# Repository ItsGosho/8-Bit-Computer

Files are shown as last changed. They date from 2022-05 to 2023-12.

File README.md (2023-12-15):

# 8-Bit-Computer
Бележки от създаването на 8-битовия компютър



- Библиотека с част от чиповете нарисувани са направени и качени в **KiCad Symbols**

- Идеята за проекта се води от книгата [Digital Computer Electronics - Albert Paul Marvino](https://www.amazon.com/Digital-computer-electronics-Albert-Malvino/dp/0070398615) и Ben Eater
- Имаме модулна архитектура - Всеки един от компонентите може да бъде изграден самостоятелно и да работи самостоятелно

- Като в нея има много компютърни архитектури, като една от тях и използваната тук е **SAP-1 (Simple as Possible)**

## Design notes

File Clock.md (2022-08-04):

# Clock:

- Синхронизира опрерациите в компютъра
- Начина по който това става е пускането на електрически сигнал през определен интервал:
- - Може да е автоматично през определен интервал. Броя пъти пускане на тока за една секунда ги измерваме в Hz-ове.
  - - Hz - Брой пъти действия за една секунда
  - - Може да забързваме честотата или пък да я забавяме
- - Може да е ръчно.
  - Може да сменяме между автоматично и ръчно

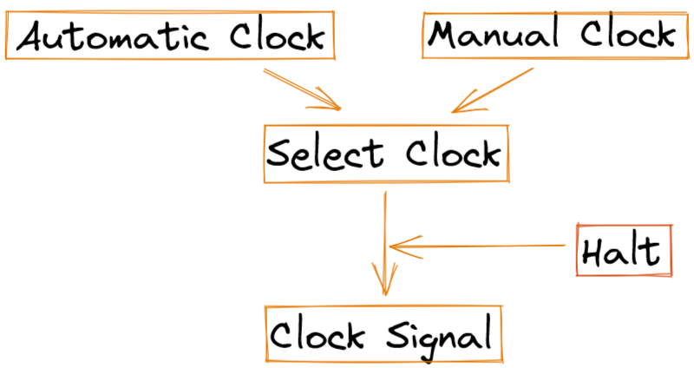
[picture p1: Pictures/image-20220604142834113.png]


### **Automatic Clock:**

- Ще работи **автоматично**. Ще подава сигнал през фиксирано време.
- Използваме за това нещо **555 Timer** в **Astable** състояние.
- **555-Timer.md**

### **Manual Clock:**

- Ще работи **ръчно**. Ние ще определяме кога да следващото подаване на сигнал.
- Използваме за това нещо **555 Timer** в **Monostable** състояние за **Debounce** на ръчният бутон.

- **Button Debouncing.md**

### **Select Clock:**

- Ще сменянме какъв да ни е **Clock-a** чрез **Switch** между **Astable** или **Monostable**
- Използваме за това нещо **555 Timer** в **Bistable** състояние за **Debounce** на Switch-a за смяната
- **Switch SPDT Debouncing.md**

### Halt: 

- Имаме **HALT** линия за **прекъсване** на **Clock-a**, която прекъсва връзката между **Select Clock** & **Clock Signal**

### Clock Signal:

- Изкарва периодичен сигнал, който синхронизира операциите ни.

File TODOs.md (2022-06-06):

1. Във файла Clock.md подробно ще опиша идеята на Clock-a.
   - Какво искаме да постигнем като цяло и какво му е идеята
   - 1 стъпка - Astable Clock - Подробно за какво идва реч
   - 2 стъпка - Monostable Clock - Подробно за какво идва реч
   - 3 стъпка -  Bistable Clock - Подробно за какво идва реч
   - Ще се постарая да сложа във кой файл може да се намери подробна информация

- Пренаредя пиновете на Clock модула

Links:

https://www.ilovefreesoftware.com/13/featured/free-websites-to-make-timing-diagram-online.html

https://circuitdigest.com/electronic-circuits/what-is-switch-bouncing-and-how-to-prevent-it-using-debounce-circuit

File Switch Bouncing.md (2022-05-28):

# **Switch Bouncing Problem:**

- При натискането на бутон е възможно за кратно да получим няколко бързи сигнала преди да се стабилизира.

- В бутона и две метални плочици, които се свързват при натискането му.
- Проблема обача е че докато се стабилизират прилипнали ще подскочат/рикошират една от друга
- Това ще доведе до няколко бързи сигнала

Пример:



### Различни варианти за справяне с този проблем:

1. **Използваме RC (Resistance-Capacitance):**



- Когато **не сме** **натиснали** бутона, то **кондензатора се зарежда през резистори R1 и R2**

- Когато **натиснем** бутона, то **кондензатора се разрежда през резистор R2**

- Когато се **разреди кондензатора**, то **напрежението пада до 0V** и **Inverter-a се пуска** и **имаме сигнал на Output**

- Цялото нещо с кондензатора ни кара да задържим малко повече бутона за да получим сигнал на **Output**-a

- **ОТ ГОЛЕМИНАТА НА КОНДЕНЗАТОРА И РЕЗИСТОРА ЗАВИСИ:**

- - С какво закъснение ще се отчете сигнала при Output след натискане на бутона
  - Колко време ще е нужно да не натискаме бутона преди следващото натискане

  **Тест**: Нека вдигнем кондензатора **(C1)** на **10** microfarad-a:

  - Сега **ако натискаме по-бързо бутона**, то **няма да имаме сигнал на Output**, защото не се е разредил кондензатора

  - Съответно трябва да го задържим малко повече за да го разредим напълно и да получим сигна на **Output**

  - Така **избягваме Bouncing-a**, тоест тези няколко бързи сигнала, които се получават, когато го задържим - няма да активират нашият изход, защото не са достатъчно дълги за да затворят веригата и разредят кондензатора напълно.

    - Както виждаме от снимката, първите ни 3 бързи натискания не са достатъчни да Discharge-нат кондезатор
    - 

**Charging**:



**Discharging**:



2. **Използваме 555 Timer:**

- При натискането на бутона:
- - Взимаме 5V-та от **-** на Set Comparator-a, като така го активираме (1.7V **+** > 0V **-**)
  - Set Comparator-a слага SR Latch-a в Output State (Q = 1) и Discharge-a спира
  - Докато е спрян Discharge-a, то няма какво да отнеме напрежението от + на Reset Comparator-a и започва да се вдигна напрежението.
  - Когато то достигне + >= 3.3V, то SR Latch-a отива в Discharge State 



- **ОТ ГОЛЕМИНАТА НА КОНДЕНЗАТОРА И РЕЗИСТОРА ЗАВИСИ ПРИ DISCHARGE-a:**
- - Каква ще е дължината на сигнала след натискането на бутона
  - Колко време ще е нужно да не натискаме бутона преди следващото натискане

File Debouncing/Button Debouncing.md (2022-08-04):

# **Button Bouncing Problem:**

- При натискането на бутон е възможно за кратно да получим няколко бързи сигнала преди да се стабилизира.

- В бутона и две метални плочици, които се свързват при натискането му.
- Проблема обача е че докато се стабилизират прилипнали ще подскочат/рикошират една от друга
- Това ще доведе до няколко бързи сигнала
- На някой дигитални устройства, който могат бързо да отговорят на сигнала това ще им създаде проблем

Пример:



### Различни варианти за справяне с този проблем:

1. **Използваме RC (Resistance-Capacitance):** (Hardware Solution)

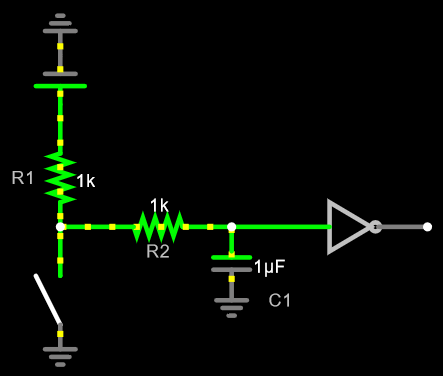
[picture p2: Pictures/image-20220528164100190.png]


- Когато **не сме** **натиснали** бутона, то **кондензатора се зарежда през резистори R1 и R2**

- Когато **натиснем** бутона, то **кондензатора се разрежда през резистор R2**

- Когато се **разреди кондензатора**, то **напрежението пада до 0V** и **Inverter-a се пуска** и **имаме сигнал на Output**

- Цялото нещо с кондензатора ни кара да задържим малко повече бутона за да получим сигнал на **Output**-a

- **ОТ ГОЛЕМИНАТА НА КОНДЕНЗАТОРА И РЕЗИСТОРА ЗАВИСИ:**

- - С какво закъснение ще се отчете сигнала при Output след натискане на бутона
  - Колко време ще е нужно да не натискаме бутона преди следващото натискане

  **Тест**: Нека вдигнем кондензатора **(C1)** на **10** microfarad-a:

  - Сега **ако натискаме по-бързо бутона**, то **няма да имаме сигнал на Output**, защото не се е разредил кондензатора

  - Съответно трябва да го задържим малко повече за да го разредим напълно и да получим сигна на **Output**

  - Така **избягваме Bouncing-a**, тоест тези няколко бързи сигнала, които се получават, когато го задържим - няма да активират нашият изход, защото не са достатъчно дълги за да затворят веригата и разредят кондензатора напълно.

    - Както виждаме от снимката, първите ни 3 бързи натискания не са достатъчни да Discharge-нат кондезатор
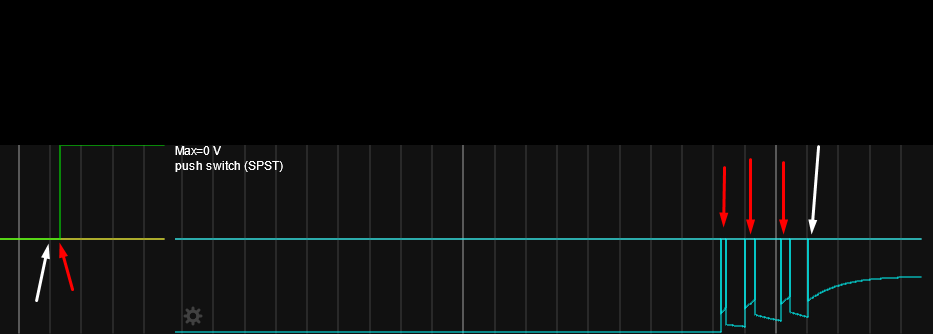
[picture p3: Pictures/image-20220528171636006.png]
    - 

**Charging**:

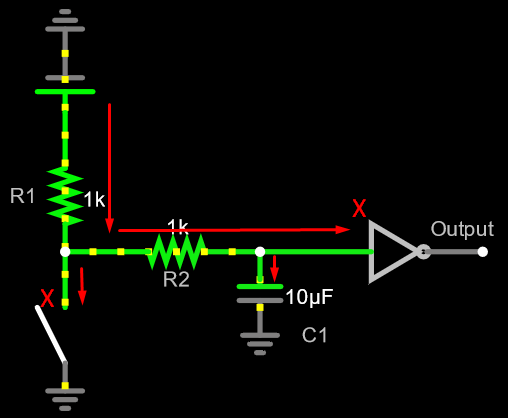
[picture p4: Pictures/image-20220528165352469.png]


**Discharging**:

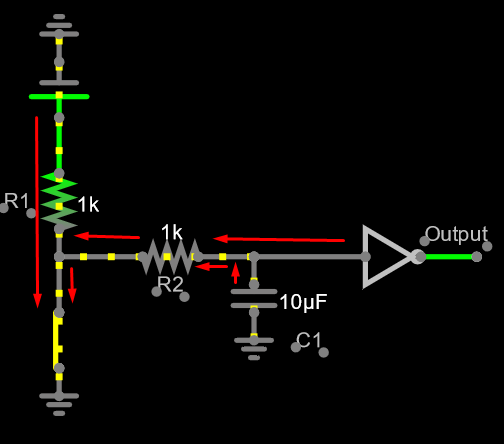
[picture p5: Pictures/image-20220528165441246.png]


2. **Използваме 555 Timer:** (Hardware Solution)

- При натискането на бутона:
- - Взимаме 5V-та от **-** на Set Comparator-a, като така го активираме (1.7V **+** > 0V **-**)
  - Set Comparator-a слага SR Latch-a в Output State (Q = 1) и Discharge-a спира
  - Докато е спрян Discharge-a, то няма какво да отнеме напрежението от + на Reset Comparator-a и започва да се вдигна напрежението.
  - Когато то достигне + >= 3.3V, то SR Latch-a отива в Discharge State 

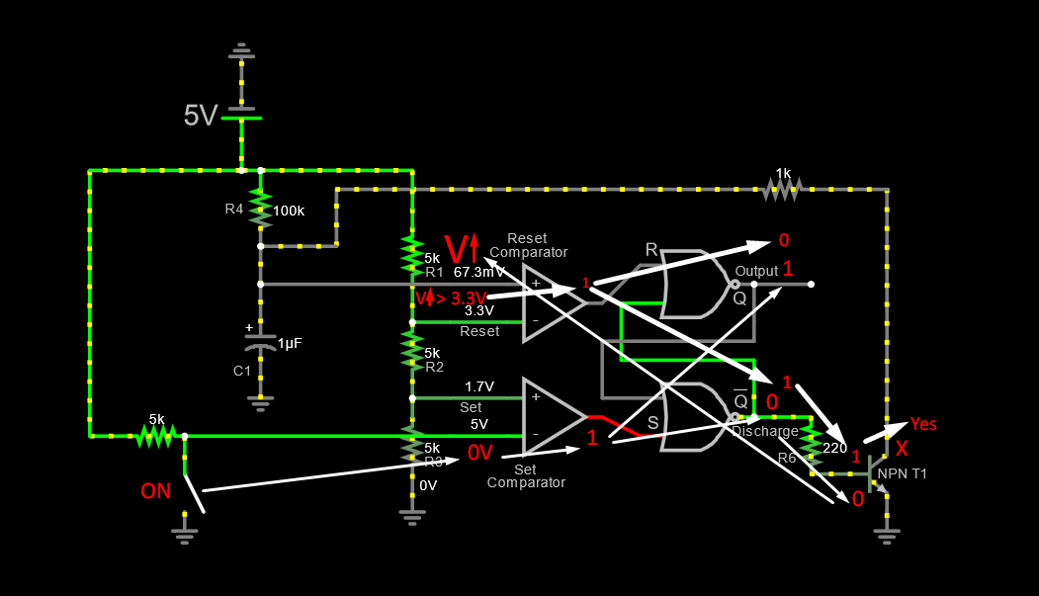
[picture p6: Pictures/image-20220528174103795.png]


- **ОТ ГОЛЕМИНАТА НА КОНДЕНЗАТОРА И РЕЗИСТОРА ЗАВИСИ ПРИ DISCHARGE-a:**
- - Каква ще е дължината на сигнала след натискането на бутона
  - Колко време ще е нужно да не натискаме бутона преди следващото натискане

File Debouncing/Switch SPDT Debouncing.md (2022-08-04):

# **Switch SPDT Bouncing Problem:**

- Switch-a избира състояние и остава на него
- При SPDT Switch-a може да избираме между две състояниа на които да останем

Bouncing:

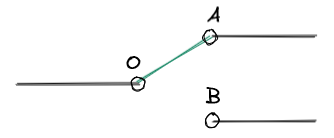
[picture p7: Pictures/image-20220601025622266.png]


- Когато сменяме от A към B или обратното от B към А се получава същото рикоширане както при Button
- Тук обаче рикоширането **НЕ е м/у двете състояния** (**A -> B**, **B -> A**, **A -> B**, **B -> A** ... **A -> B**):



- Рикоширането **Е между новото състояние е междинно такова**:

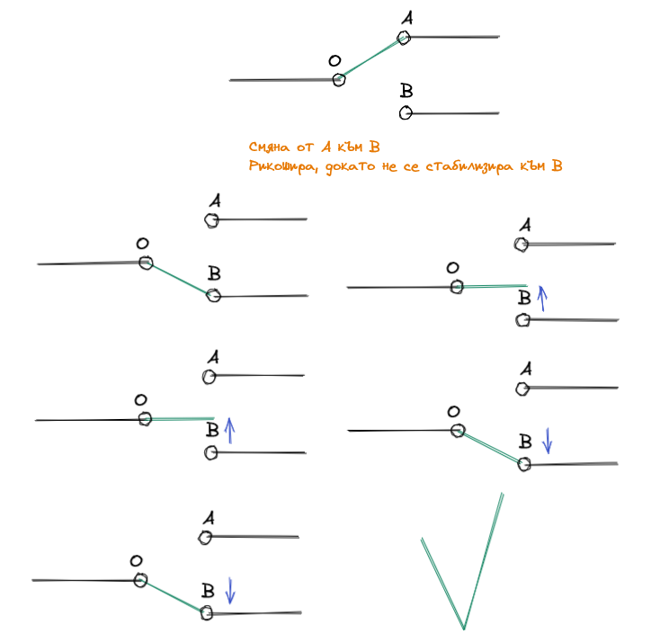
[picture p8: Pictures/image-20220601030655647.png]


### Различни варианти за справяне с този проблем:

1. **SR Latch:**

- Ако използваме SR Latch, който два входа да са свързани към тези на SPDT Switch-a лесно си решаваме проблема.
- Това става така, защото когато сменим от едно състояние в друго и се получи Bouncing-a от новото състояние към междинното:
- - SR Latch изхода няма да се промени, колкото и пъти да се подава новия вход от нулев такъв след първоначалното

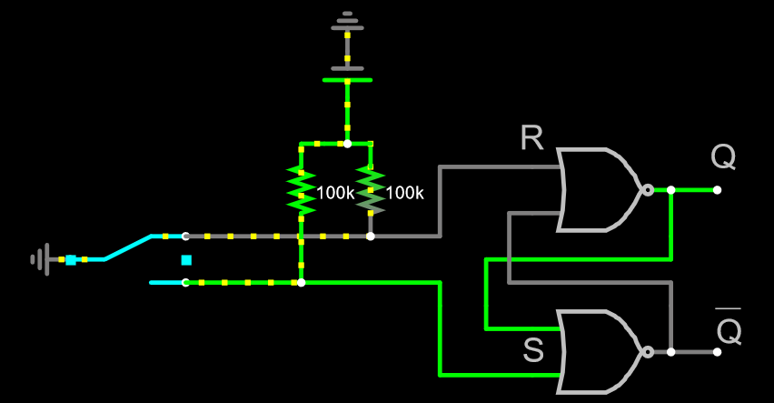
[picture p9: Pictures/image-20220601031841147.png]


- Резисторите нарочно са там, а не само един към Ground, защото когато влезе в междинно състояние няма да имаме никакво съпротивление
- Вече SPDT Switch-a ни става дигитален.

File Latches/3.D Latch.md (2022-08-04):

# D Latch:

- **D Latch** е акроним на **Data Latch**

- То е **Multivibrator** от тип **Bistable**

- Реализира се с **SR Latch**, *2 бр.* **AND Gate**, **Inverter**.

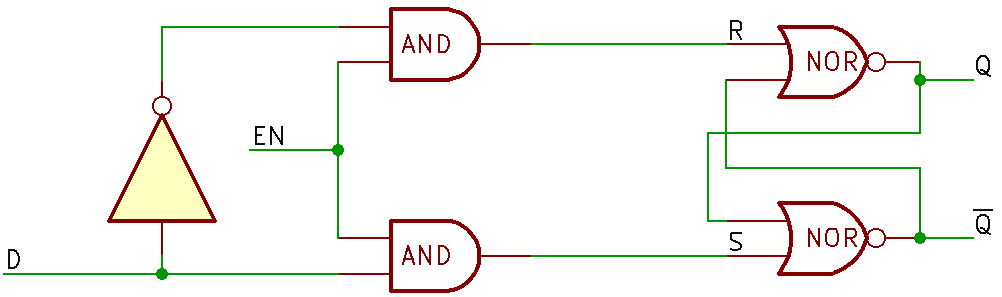
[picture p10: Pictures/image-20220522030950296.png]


**D Latch** в [CircuitJS](https://www.falstad.com/circuit/circuitjs.html)

- Чрез експериментиране може да видим какво се случва във веригата
- Файл: **/CircuitJS/d_latch.circuitjs.txt**

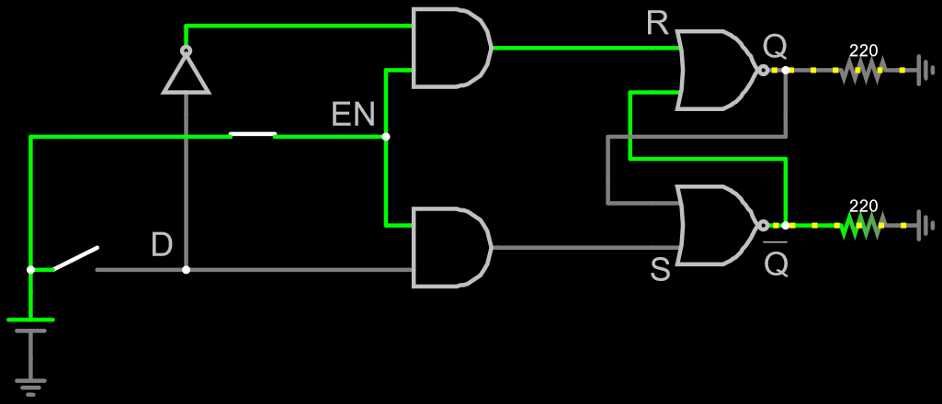
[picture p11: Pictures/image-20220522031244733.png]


- Той **надгражда SR Latch**, като позволява да определяме **дали може да се сменя състоянието на Latch-a чрез EN** и смяната на състоянието да става чрез **един вход** **D**
- Отново **не знаем** **началното** **състоянието** на **SR Latch**, ако **EN не е включен**.
- **Винаги** при подаването на **EN** без **D**,  Latch-a ще премине в **Reset (R)** състояние **заради Inverter-a**, който **постоянно подава сигнал**.
- Как би **изглеждал изхода** от **D Latch** при **примерно** подаване на сигнали:
- - **[DrawIo](https://app.diagrams.net/)** Timing Diagram
  - Файл: **/DrawIo/D_Latch_Timing_Diagram.drawio**

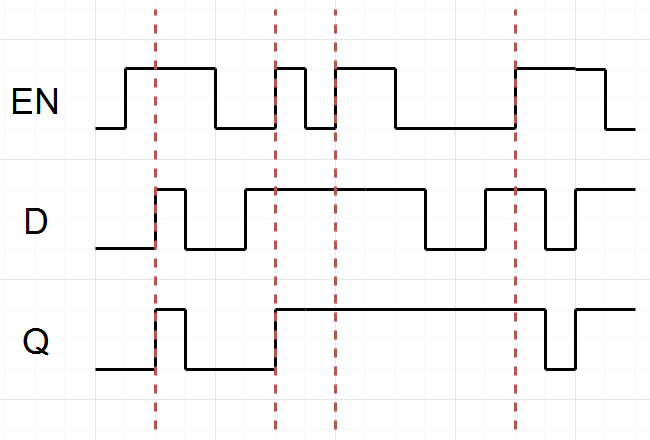
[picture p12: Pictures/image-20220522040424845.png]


- Както виждаме от диаграмата, *изхода* на **Q** *зависи* от D, което *зависи* от **EN**. 

- Когато **EN** е включен, то **Q** *следва* **D** *1:1*, ако **EN** бъде **изключен** то **Q** остава **последното състояние** на **D**.

| EN | D | Q | Q Inverted |
| ---- | ---- | ---- | :--- |
| 0 | 0 | Q | Q Inverted |
| 0 | 1 | Q | Q Inverted |
| 1 | 0 | 0 | 1 |
| 1 | 1 | 1 | 0 |

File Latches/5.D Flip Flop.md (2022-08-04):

# **D Flip Flop**

- То е **Multivibrator** от тип **Bistable**
- **Надгражда** D Latch, като се реализира с **Clock** вместо **Enable (EN)**

**D Flip Flop** в [CircuitJS](https://www.falstad.com/circuit/circuitjs.html)

- Чрез експериментиране може да видим какво се случва във веригата
- Файл: **/CircuitJS/d_flip_flop.circuitjs.txt**

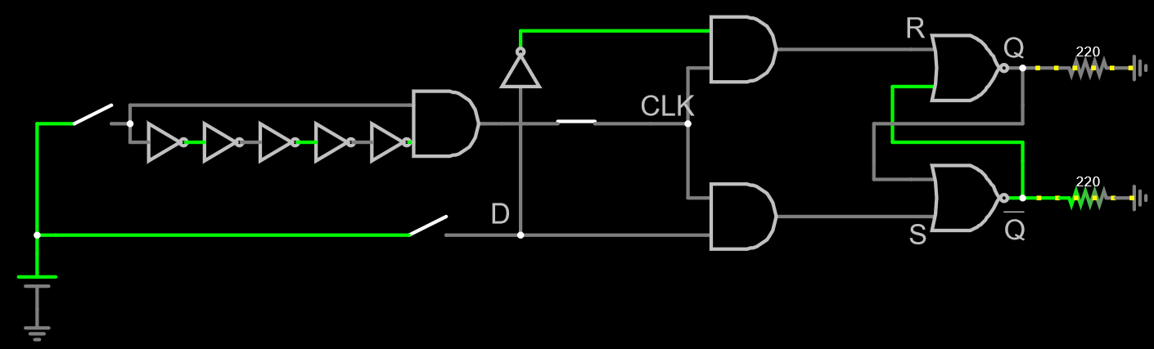
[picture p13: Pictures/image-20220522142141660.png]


- Как би **изглеждал изхода** от **D Flip Flop** при **примерно** подаване на сигнали:
- - **[DrawIo](https://app.diagrams.net/)** Timing Diagram
  - Файл: **/DrawIo/D_Flip_Flop.drawio**

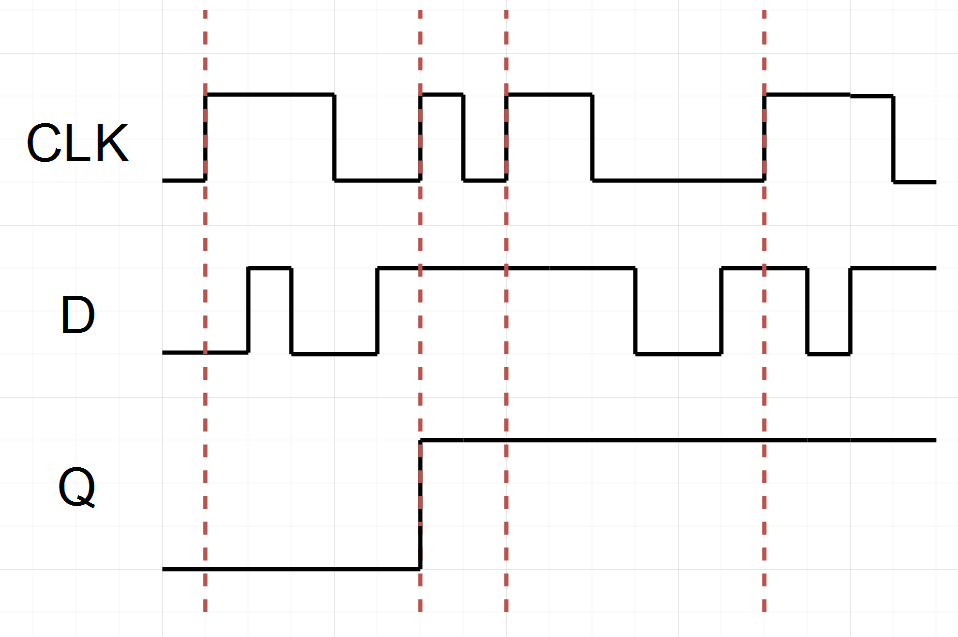
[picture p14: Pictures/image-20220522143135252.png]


| CLK  | D | Q | Q Inverted |
| ---- | ---- | ---- | --- |
| 0 | 0 | Q | Q Inverted |
| 0 | 1 | Q | Q Inverted |
| 1 | 0 | 0 | 1 |
| 1 | 1 | 1 | 0 |

- Таблицата е същата с тази на **D Latch**, но вече сигнала се **взима** само при **първоначалното** подаване на **сигнал**.

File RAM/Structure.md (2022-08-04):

# Structure:

### Address Module:

- В нашият модул, който използваме за паметта (**IC 74189 64 Bit RAM**) вече имаме изградена система за адресиране *(избиране на ред/адрес от паметта)*.

- Тази система за адресиране се състои от **4** входа, като те **бинарно** репрезентират **адрес/ред** в **паметта**.

- - Имаме входове **A0**,**A1**,**A2**,**A3**. Ако **искаме да изберем даден адрес** ще трябва да подадем **следните стойности на входовете**:

  - | A0   | A1   | A2   | A3   | Address |
    | ---- | ---- | ---- | ---- | ------- |
    | 0    | 0    | 0    | 0    | 0       |
    | 1    | 0    | 1    | 0    | 10      |
    | 0    | 1    | 1    | 1    | 7       |
    | 1    | 1    | 1    | 1    | 15      |

  - **Как се декодират и менажират адресите в паметта**, може да видим в **RAM-Idea.md**

- Въпреки, че **вече имаме изградена система** за адресиране в **IC 74189** ние **искаме да я надградим**:
- - Ръчен режим - ръчно ще изберем адрес от паметта
  - Автоматичен режим - на следващият clock сигнал от bus-a ще дойде адреса

#### Реализиране:

- Ще **сменяме режимите**  между *автоматичен* и *ръчен* с прост **Slide Switch**
- Ще имаме **LED индикация** в **кой режим се намираме** (*автоматичен*, *ръчен*)
- Ще имаме **4 битов DIP Switch** за **избиране на адрес при ръчен режим**.
- Ще имаме **74LS157 Quad 2-1 Line Mux**, който избира от коя страна (*автоматична*, *ръчна*) ще се взима сигнала
- - Работи  точно като дигиталният Switch, който правих. Тук имаме няколко канала между, които се сменя.
  - *CircuitJS/digital_switch_simplified.circuitjs.txt*
  - Примерно имаме **A0**,**B0**,**A1**,**B1** **входове** за сигнал, **Y0** и **Y1** **изходи** за резултат и **Select** вход за избор.
  - Ако **Select = 1**, то **Y0 = A0** и **Y1 = A1**
  - Ако **Select = 0**, то **Y0 = B0** и **Y1 = B1** 
- Ще имаме **74LS173 4-Bit D Register**, който ще ни помогне за това  да имаме **Clock** в **Address Module**-a.

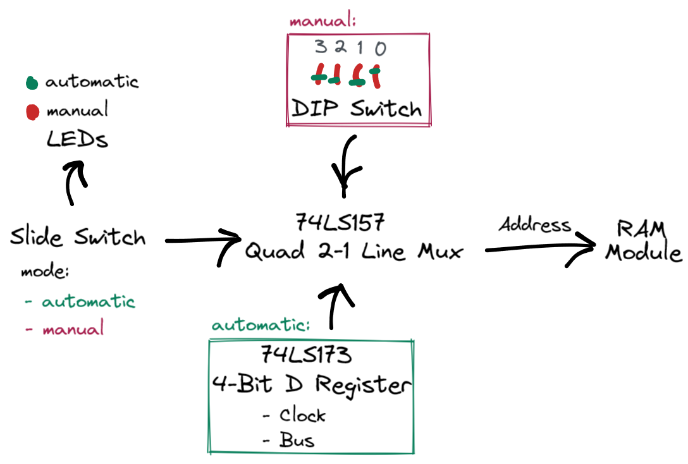
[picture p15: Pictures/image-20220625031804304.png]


### Data Module:

- В нашият модул, който използваме за паметта (**IC 74189 64 Bit RAM**) вече имаме изградена система за залагане на данни по избран адрес.
- Въпреки, че **вече имаме изградена система** за залагане на данни по избран адрес в **IC 74189** ние **искаме да я надградим**:
- - Ръчен режим - ръчно ще заложим данните на избран адрес
  - Автоматичен режим - на следващият clock сигнал от bus-a ще дойдат данните за избарния адрес

#### Реализиране:

- Ще използваме **Slide Switch**-a от **Address Module** за смяна на режимите (*автоматичен*/*ръчен*)
- Ще използваме същата **LED** индикация от **Address Module**
- Ще имаме **8 битов DIP Switch** за **избиране на данни при ръчен режим**.
- Ще имаме **Push Button**, който ще е **активен в ръчен режим** и при **натискане ще запише избраните данни на избрания адрес**
- Ще използваме **3** броя **74LS157 Quad 2-1 Line Mux**:
- - **2** **от тях** ще са за данните (от къде идват)
  - **1 от тях** ще е за записващият сигнал:
  - - Ръчен режим - **Push Button**
    - Автоматичен режим - **Clock**

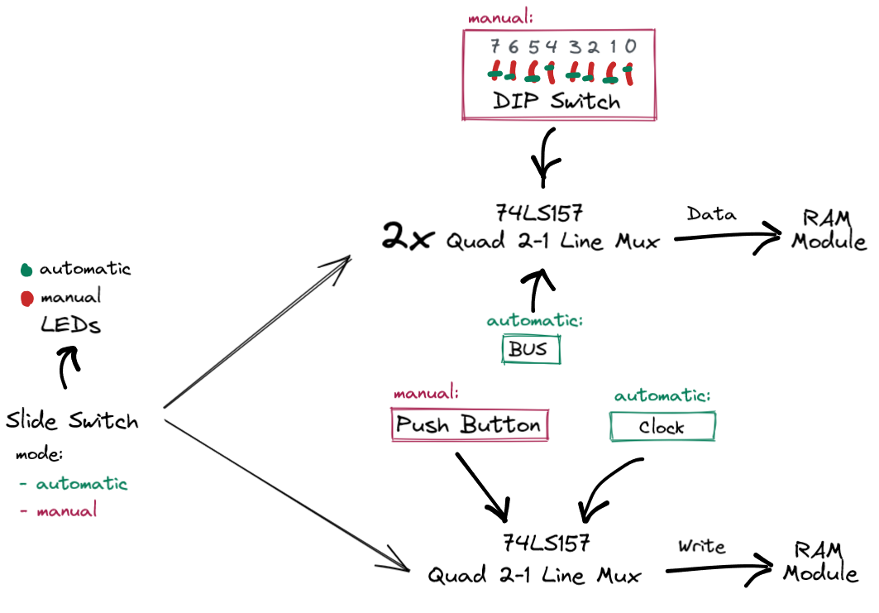
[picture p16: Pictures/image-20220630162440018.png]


#### Проблеми:

- **1:** 
  - Със стандартният дизайн при смяна на режимите (ръчен/автоматичен) често trigger-ваме write сигнала.
  - Това се получава от 74LS157 Quad 2-1 Line Mux. 
  - При смяна на Line дори и двата сигнала пр. A0 и B0 да са HIGH, то Y0 ще премине през LOW за кратко време, което време е достатъчно да trigger-не write-a на паметта.

- **2:**
  - Със стандартният дизайн използваме RC (Resistor-Capacitor) за да хванем Rising Edge-a на Clock-a.
  - Това нещо също довежда до проблеми по-нагоре.

**Реш. 1:**

- Push Button-a ще подава HIGH сигнал към 74LS157
- Clock-a също ще подава HIGH сигнал към 74LS157
- Резултата от 74LS157 ще бъде обърнат HIGH -> LOW, което ще активира записването

**Реш. 2:**

- Използваме останалите свободни пинове на 74LS00 (NAND Gate) и 74LS04 (Inverter) за да хванем Rising Edge-a на Clock.
- Ако закачим един и същи сигнал към двата входа на NAND Gate-a ще обърнем сигнала т.е може да го използваме като Inverter
- Ако закачим два входа към двата входа на NAND Gate-a и резултата го обърнем (т.е го закачим пак) ще получим AND от двата входа

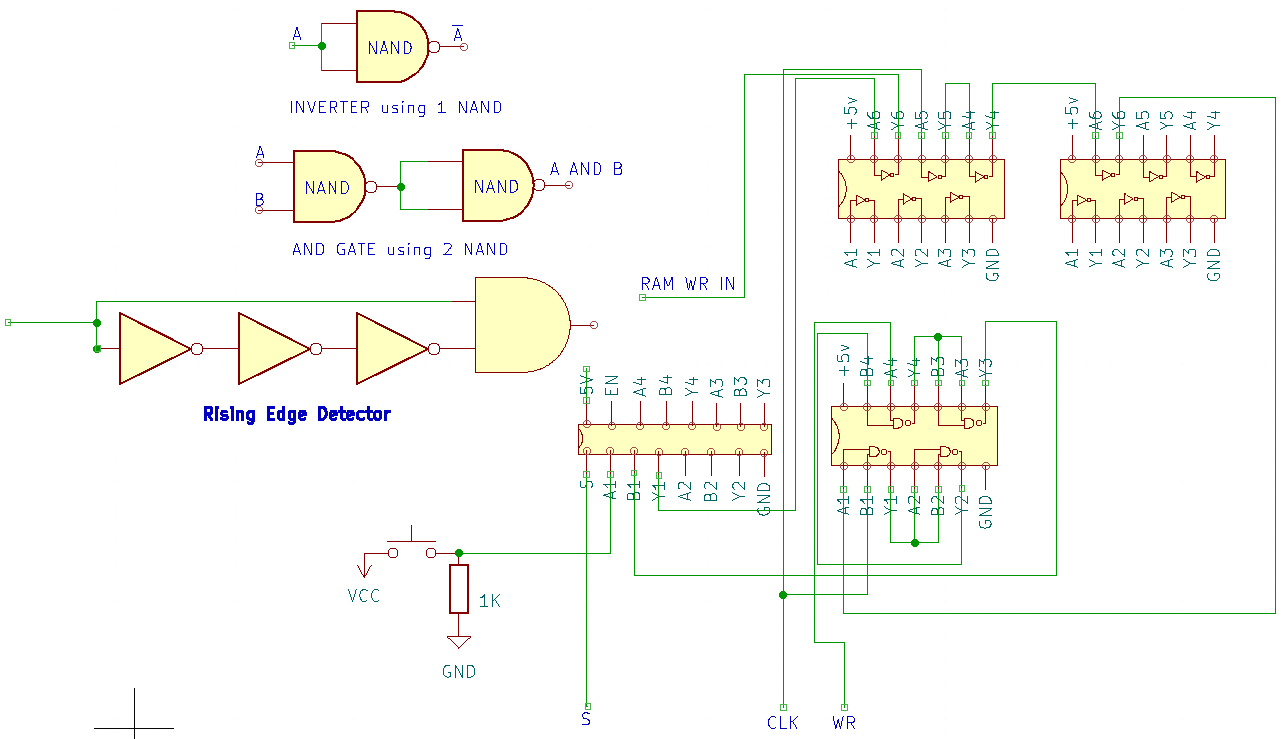
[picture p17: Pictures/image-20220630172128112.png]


### RAM Module:

- Имаме **2** бр. **74189: 64-bit RAM (4-bit words)**
  - Адресите им са свързани една с друга
  - Адресите им са свързани с **Address Module**
  - Единият държи **долните 4 бита**, а другият **горните 4 бита**.
  - Входа на данните е свързан с **Data Module**. Така имаме **16 броя 8-bit words**.
  - Изходите са свързани с **74LS04: Inverter**, защото на този чип изхода ни дава данните обърнати
  - Вече нормализираните данни чрез **74LS04: Inverter** са свързани с **74LS245: 8-bit bus transceiver** за да може правилно да ги изкараме на буса
- Имаме **2** бр. **74LS04: Inverter** за нормализиране на данните от рамта преди пускането на бус лентата.
  - Част от неговите входове, които не се използват при **RAM Module** се използват при **Data Module** за да ни помагнат да отстраним проблеми там
- Имаме **1** бр. **74LS245: 8-bit bus transceiver** за **правилна комуникация с бус лентата**

### Summary:

Имаме **Switch**, който сменя режимите между **ръчен** и **автоматичен**. Когато изберем режим адреса и данните ще дойдат или от нас през **DIP Switch**-овете или от **BUS** лентата. При ръчният режим след като сме избрали адрес и данни, натискаме **Push Button**-a и записваме на избраният адрес данните.

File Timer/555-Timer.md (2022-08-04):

# 555 Timer:

- Генерира електрически сигнал през определено време.
- Има две състояния Charging (Output), Discharging (No output)

Според информацията, която намерих в интернет за неговите "вътрешности" направих опит да го направя в **[CircuitJS](https://www.falstad.com/circuit/circuitjs.html)**, но изникнаха проблеми и се наложи да го преправя.

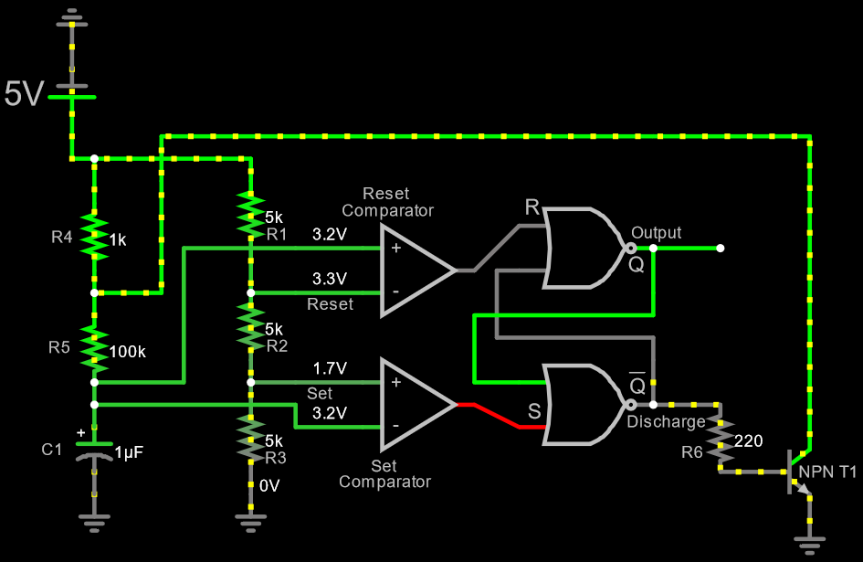
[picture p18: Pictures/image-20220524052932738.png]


- Resistor 1 (1k) променя само Time High
- Resistor 2 (100k) променя Time High и Time Low
- Capacitor (1u) променя Time High и Time Low значително

1. Създаваме **Voltage Divider** с **3** бр. 5k резистора:

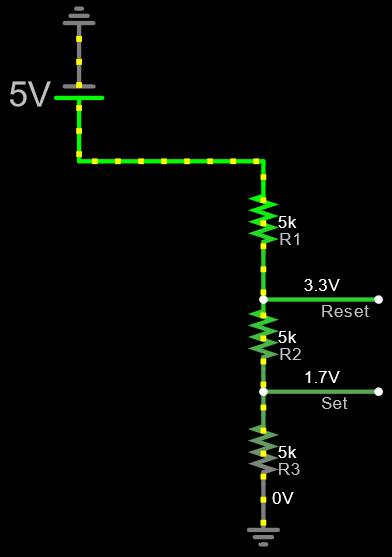
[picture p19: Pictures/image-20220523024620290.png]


- Идеята е да получим **различни нива на напрежение** м/у резисторите, който ще ни **служат за Comparator-ите после**.

2. Залагаме **2** бр. Comprator-и, които ще използваме за **Set & Reset** на бъдещият **SR Latch**.

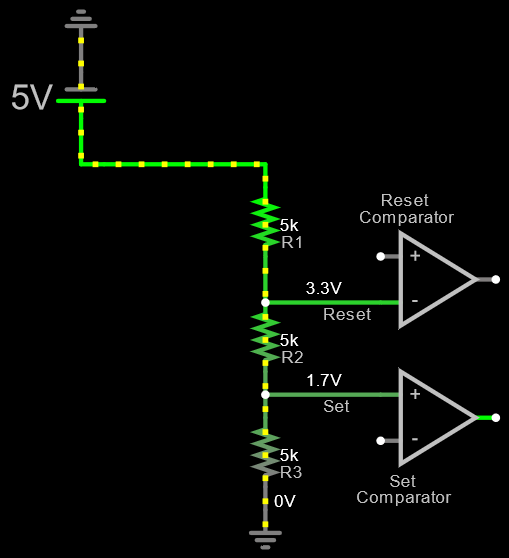
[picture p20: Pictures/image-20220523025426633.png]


- **Comparator сравнява напрежения**. Ако това на **+ > -** , то Comparator-a ще се активира и ще пуска ток, докато това условие е валидно.
- В нашият случай:
- - *Reset Comparator + > 3.3V*
  - *Set Comparator 1.7V > -*

3. Залагаме **SR Latch**, който ще ни позволи да запазим **двете нужни състояния** на нашият **555 Timer**:

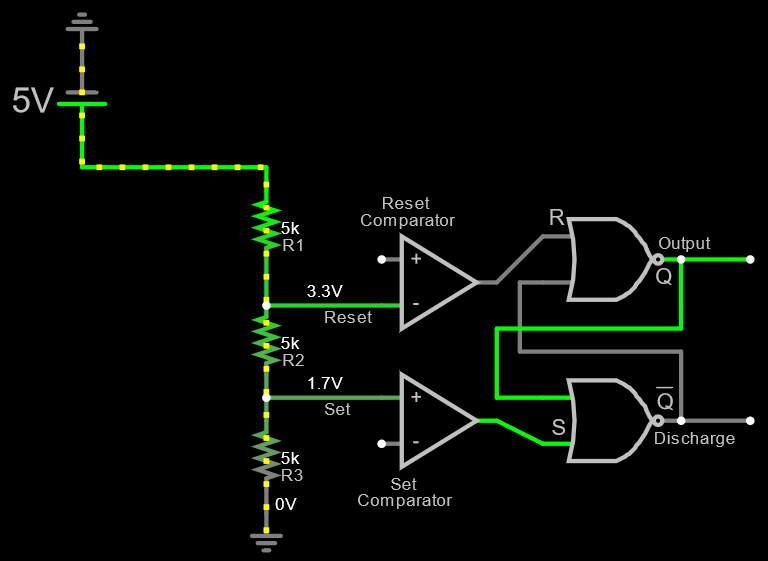
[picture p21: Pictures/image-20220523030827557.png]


- **SR Latch**-a ни е нужнен да **запомним** в което състояние се намираме - **Output** или **Discharge**
- При **Output** и **Discharge** периодите, **Reset** и **Set Comparator**-ите няма да бъдат активни. Затова използваме **SR Latch-a** да запомним **последното състояние** което е било избрано.

| Period | Reset Comparator + Voltage | Set Comparator - Voltage |
| --- | --- | --- |
| Output | Спада от 3.3V до 1.7V | Набира от 1.7V до 3.3V |
| Discharge | Набира от 1.7V до 3.3V | Спада от 3.3V до 1.7V |

4.  Основната контролираща линия:

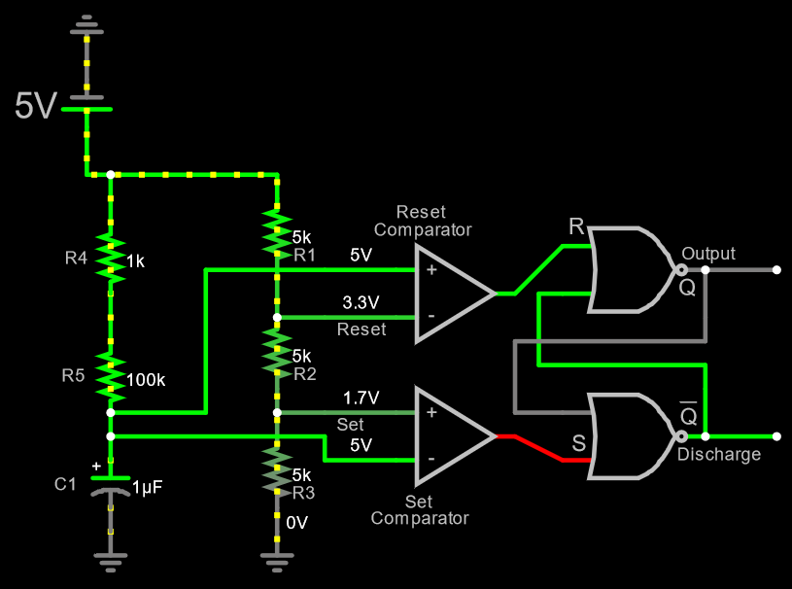
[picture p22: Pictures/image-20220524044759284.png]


- Заложи ли сме **2** бр. резистори в серия и **1** бр. кондензатор в серия с резисторите.
- Така ще **забавим времето за зареждане на кондензатора**, като това ще ни позволи **напрежението преди него да се качва по-бавно**.
- *Времето за качване на напрежението зависи от големината на кондензатора и съпротивлението в серия с него.*
- Note: Първият резистор (1K) е сложен нарочно, защото ще ни е нужен за Discharge логиката после.

5. Discharge логика:

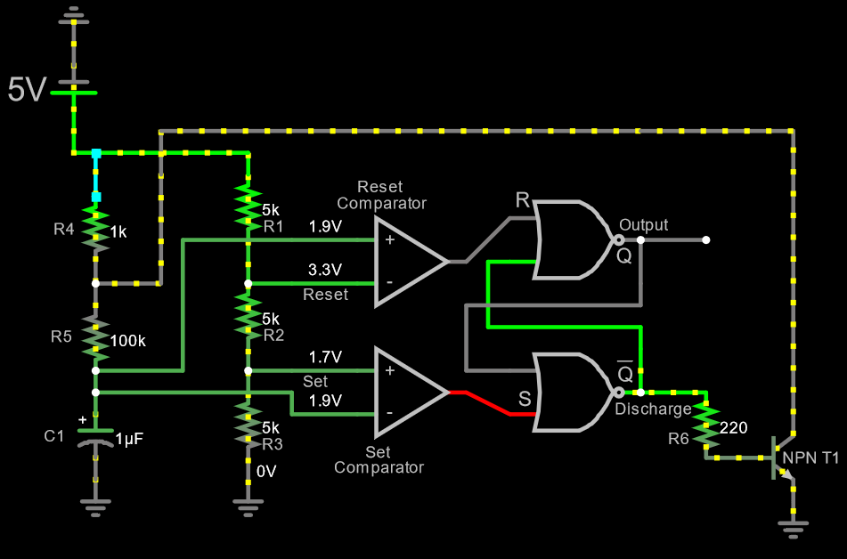
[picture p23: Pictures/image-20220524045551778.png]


- Залагаме, когато имаме състояние на **Discharge** при **SR Latch-a** да активираме **NPN Transistor**.
- NPN Transistor-a при активиране ще свързва **основната контролираща линия** с Ground.
- Когато се отвори **Discharge** линията, то тока от пътя **5V -> R4 -> R5 -> Reset Comparator, Set Comparator и C1** няма да следва този път вече, защото този на **Discharge** линията е с **по-малко съпротивление**.  Съотвено новият му път е **(5V -> R4 -> NPN T1 -> Ground)**
- **R5, C1, Reset Comparator и Set Comparator** ще загубят напрежение заради новата линия **5V -> R4 -> NPN T1 -> Ground** и тогава ще се активира **C1**. Вече имаме нова линия **C1 -> R5, Reset Comparator, Set Comparator -> NPN T1 -> Ground**. Сега постепенно напрежението на Reset Comparator и Set Comparator ще спада, докато отново не се активира Set Comparator-a. Тогава целият цикъл започва отначало.

**Charging Flow:**

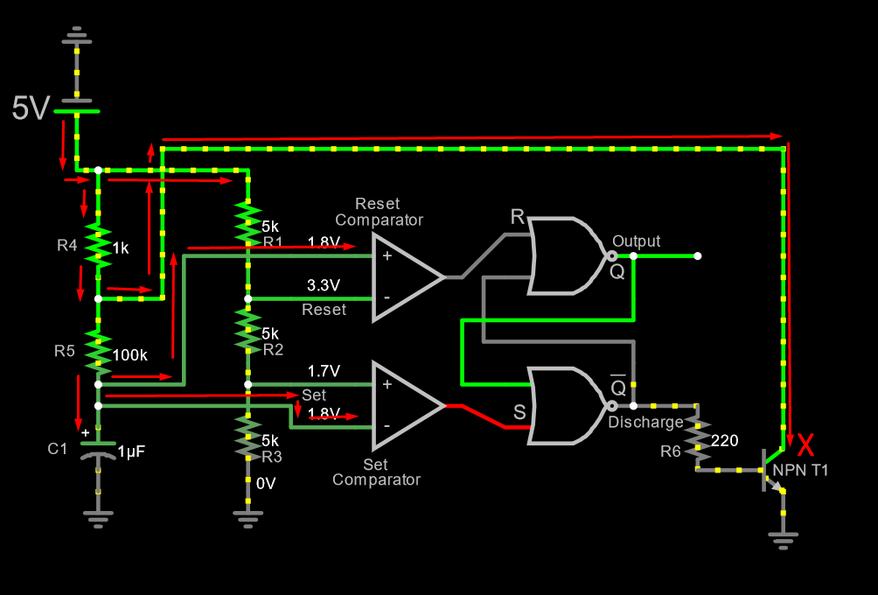
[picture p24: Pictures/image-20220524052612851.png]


**Discharging Flow:**



https://www.digikey.bg/en/resources/conversion-calculators/conversion-calculator-555-timer

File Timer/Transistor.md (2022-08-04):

https://www.seeedstudio.com/blog/2020/03/11/what-is-a-transistor-types-uses-working-principle/

https://learn.sparkfun.com/tutorials/transistors/all

https://www.physics-and-radio-electronics.com/electronic-devices-and-circuits/transistors/bipolarjunctiontransistor/bjtoperationmodes.html

https://www.allaboutcircuits.com/textbook/experiments/chpt-5/simple-op-amp/

https://www.youtube.com/watch?v=zpyK5Hy8d0c

https://www.youtube.com/watch?v=J4oO7PT_nzQ

- Чакам да дойдат PNP & NPN транзисторите за да мога да започна да ги ръчкам



1. Защо при еднакво напрежение и съпротивление имаме разлика във напрежението, когато е включен транзистор?







Изводите, които си правя тук:

- Emitter Current = Base Current + Collector Current

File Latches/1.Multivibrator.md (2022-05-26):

# Multivibrators:

- Идеята им е да задържат различни електрически състояния.
- Делят се на **3** категории:
- - **Bistable** - Имае **две** **стабилни** състояния 1 или 0 (**S-R Latch**, **D Latch**, **D Flip-Flop**)
  - **Monostable** - Има **едно** **стабилно** състояние (**Rising Edge Detector**)
  - **Astable** - Няма стабилно състояние. Постоянно сменя 1 или 0

### Resources:

**SR Latch:**

[Ben Eater]: https://www.youtube.com/watch?v=KM0DdEaY5sY&amp;list=PLowKtXNTBypGqImE405J2565dvjafglHU&amp;index=6
[All About Circuits]: https://www.allaboutcircuits.com/textbook/digital/chpt-10/s-r-latch/

**D Latch:**

[Ben Eater]: https://www.youtube.com/watch?v=peCh_859q7Q&amp;list=PLowKtXNTBypGqImE405J2565dvjafglHU&amp;index=7
[All About Circuits]: https://www.allaboutcircuits.com/textbook/digital/chpt-10/d-latch/

**D Flip Flop:**

[Ben Eater]: https://www.youtube.com/watch?v=YW-_GkUguMM&amp;list=PLowKtXNTBypGqImE405J2565dvjafglHU&amp;index=8
[All About Circuits]: https://www.allaboutcircuits.com/textbook/digital/chpt-10/edge-triggered-latches-flip-flops/

**Other useful:**

[Latch Circuits Questions]: https://www.allaboutcircuits.com/worksheets/latch-circuits/

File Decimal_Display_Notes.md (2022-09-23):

1. Искахме да обърнем бинарен вход репрезентиращ число пр. 0101 към десетично число 0101 -> 5
2. Имахме дисплейче (7 segment LED Display), което визуализира 7 различни чертички, като това коя ще се покаже зависи на кое от пинчетата му е подаден ток.
3. Съответно това дисплейче може лесно да визуализира стойности от 0 до 9 вкл.
4. Създаваме си една булева таблица между всички входове бинарни числа и нужните пинове които трябва да са пуснати на дислея за да го визуализира
5. Може лесно да създадем верига, която да изпълнява този combinational logic
6. Обаче нещата ще станат по-сложи, когато искаме да визуализираме 8 битово число като десетично, защото ще ни трябват 3 такива дисплея за да покажат нещо от 0 до 255.
7. Сложи, защото булевата таблица става гиганстска и веригака която трябва да създадем колосална
8. Тогава идва на помощ EEPROM, което е проста рам.
9. Обаче ние при булевите таблици имаме даден вход и изход
10. При рамта имаме адреси и стойност срещу тях
11. Може да използваме адресите на паметта да репрезентираме входа от булевата таблица, а стойноста на този адрес - изхода от булевата таблица
12. Само трябва предварително да сложим на ръка при даден вход какъв изход ще имам и сме готови
13. Още по-лесният вариант е да си напишем програм, която да пълни EEPROM-a автоматично за нас. Въпреки, че дори и след power off държи стойностите в него, то е по-лесно да си направим програма, която да го пълни. Така лесно може да имплементираме алгоритъм, който ни е нужен на нас.

EEPROM Programmer - Предварително записана памет с някакви данни.

- Как тези EEPROM програматори се различават от това да си го направя с Arduino ?!
- Ще напиша много готина и лесна за използване библиотека (един файл) за програмирането на 28C16 EEPROM-a

7 Segment Decimal Display: LTS547R



- След подаването на сигнал на даден PIN светва съответната чертичка.
- Примерно за да изобразим 7, ще трябва да подадем ток на пинове 3,4,1,7

- От тук може да си създадем таблица:

| Number | Pin 1 | Pin 2 | Pin 3 | Pin 4 | Pin 5 | Pin 6 | Pin 7 |
| --- | --- | --- | --- | --- | --- | --- | --- |
| `0` | *LOW* | **HIGH** | **HIGH** | **HIGH** | **HIGH** | **HIGH** | **HIGH** |
| `1` | *LOW* | *LOW* | *LOW* | **HIGH** | *LOW* | *LOW* | **HIGH** |
| `2` | **HIGH** | LOW | **HIGH** | **HIGH** | **HIGH** | **HIGH** | *LOW* |
| `3` | **HIGH** | *LOW* | **HIGH** | **HIGH** | *LOW* | **HIGH** | **HIGH** |
| `4` | **HIGH** | **HIGH** | *LOW* | **HIGH** | *LOW* | *LOW* | **HIGH** |
| `5` | **HIGH** | **HIGH** | **HIGH** | LOW | LOW | **HIGH** | **HIGH** |
| `6` | **HIGH** | **HIGH** | **HIGH** | LOW | **HIGH** | **HIGH** | **HIGH** |
| `7` | *LOW* | *LOW* | **HIGH** | **HIGH** | *LOW* | *LOW* | **HIGH** |
| `8` | **HIGH** | **HIGH** | **HIGH** | **HIGH** | **HIGH** | **HIGH** | **HIGH** |
| `9` | **HIGH** | **HIGH** | **HIGH** | **HIGH** | *LOW* | *LOW* | **HIGH** |

- Ние работим с бинарни числа в нашият 8 битов компютър.
- Съответно максималното число, което можем да трансферираме е 8 битово. 
- 8 бита могат да репрезентират като десетично число 1111 1111 = 255
- Нека да приемем, че нашият компютър е 3 битов, което означава максимална десетична стойност 111 = 7
- Искаме да визуализираме тази 3 битова стойност като десетично число на нашият дисплей. Може да си създадем булева таблица, която да репрезентира при дадена стойност от буса, кои пинове ще трябва да бъдат пуснати на дисплея за да визуализира стойноста правилно.

| Bus (Binary Value) | Display (Pins 1/7) |
| --- | --- |
| 000 **(0)** | 0111111 |
| 001 **(1)** | 0001001 |
| 010 **(2)** | 1011110 |
| 011 **(3)** | 1011011 |
| 100 **(4)** | 1101001 |
| 101 **(5)** | 1110011 |
| 110 **(6)** | 1110111 |
| 111 **(7)** | 0011001 |

- Тази Combination Logic може да бъде реализира по два начина:
  - Чрез Logic Gates, както сме реализирали друга булева логика до сега
  - Чрез EEPROM, където адреса е лявата страна от една булева таблица, а стойноста на адреса - очакваната.

- Сега ще трябва да се измисли начин да визуализирам 8 битови стойности, което означава числа до 255.
- Обаче ние разполагаме с Two's Completement, което означава, че първият ни бит сигнализира дали числото е положително (0) или отрицателно (1)
- Съответно ще имаме числа до 7 бита = 127
- Ще са ни нужни 4 такива дисплей. 
- Първият ще е за знака, ако е положително няма да има нищо, а ако е отрицателно - чертичкa
- Вторият ще е за мястото на 100-ните
- Третият ще е за мястото на 10-тите
- Четвъртия ще е за мястото на 1-ците

- Обаче сега идва проблема, че имам само един EEPROM, който може да изкара стойност само до 8 бита, а тук общият брой на битовете нужни за контролирането на 4 броя дисплей, които ще изискват 4 * 7 = 28 броя комбинация от битове.



Пинове A7 до A0 репрезентират 8 битовото число (Two's Complemet).

Пинове A9 до A8 е комбинацията за позициите на цифрите.

| A10  | A9 | A8 | A7 | A6 | A5 | A4 | A3 | A2 | A1 | A0 | DEC  | I/O7 | I/O6  | I/O5  | I/O4  | I/O3  | I/O2  | I/O1  | I/O0  | SYM  |
| ---- | ----- | ----- | ---- | ---- | ---- | ---- | ---- | ---- | ---- | ---- | ---- | ---- | ----- | ----- | ----- | ----- | ----- | ----- | ----- | ---- |
| | **0** | **0** | 0 | 1 | 0 | 0 | 0 | 0 | 0 | 1 | +129 | | **H** | *L* | *L* | **H** | **H** | **H** | **H** | 9 |
| | **0** | **1** | 0 | 1 | 0 | 0 | 0 | 0 | 0 | 1 | +129 | | *L* | **H** | **H** | **H** | **H** | *L* | **H** | 2 |
| | **1** | **0** | 0 | 1 | 0 | 0 | 0 | 0 | 0 | 1 | +129 | | **H** | *L* | *L* | **H** | *L* | *L* | *L* | 1 |
| | **1** | **1** | 0 | 1 | 0 | 0 | 0 | 0 | 0 | 1 | | | *L* | *L* | *L* | *L* | *L* | *L* | *L* | X |
| | | | | | | | | | | | | | | | | | | | | |
| | **0** | **0** | 0 | 1 | 0 | 1 | 0 | 1 | 1 | 1 | +87  | | **H** | *L* | *L* | **H** | **H** | *L* | *L* | 7 |
| | **0** | **1** | 0 | 1 | 0 | 1 | 0 | 1 | 1 | 1 | +87  | | **H** | **H** | **H** | **H** | **H** | **H** | **H** | 8 |
| | **1** | **0** | 0 | 1 | 0 | 1 | 0 | 1 | 1 | 1 | +87  | | **H** | **H** | **H** | **H** | **H** | **H** | *L* | 0 |
| | **1** | **1** | 0 | 1 | 0 | 1 | 0 | 1 | 1 | 1 | | | *L* | *L* | *L* | *L* | *L* | *L* | *L* | X |
| | | | | | | | | | | | | | | | | | | | | |
| | **0** | **0** | 0 | 0 | 0 | 0 | 0 | 0 | 1 | 1 | +3 | | **H** | **H** | *L* | **H** | **H** | *L* | **H** | 3 |
| | **0** | **1** | 0 | 0 | 0 | 0 | 0 | 0 | 1 | 1 | +3 | | **H** | **H** | **H** | **H** | **H** | **H** | *L* | 0 |
| | **1** | **0** | 0 | 0 | 0 | 0 | 0 | 0 | 1 | 1 | +3 | | **H** | **H** | **H** | **H** | **H** | **H** | *L* | 0 |
| | **1** | **1** | 0 | 0 | 0 | 0 | 0 | 0 | 1 | 1 | | | *L* | *L* | *L* | *L* | *L* | *L* | *L* | X |
| | | | | | | | | | | | | | | | | | | | | |
| | **0** | **0** | 0 | 0 | 0 | 0 | 0 | 0 | 1 | 1 | -3 | | **H** | **H** | *L* | **H** | **H** | *L* | **H** | 3 |
| | **0** | **1** | 0 | 0 | 0 | 0 | 0 | 0 | 1 | 1 | -3 | | **H** | **H** | **H** | **H** | **H** | **H** | *L* | 0 |
| | **1** | **0** | 0 | 0 | 0 | 0 | 0 | 0 | 1 | 1 | -3 | | **H** | **H** | **H** | **H** | **H** | **H** | *L* | 0 |
| | **1** | **1** | 0 | 0 | 0 | 0 | 0 | 0 | 1 | 1 | | | *L* | *L* | *L* | *L* | *L* | *L* | **H** | - |

- A10 до A0 са адресните пинове на EEPROM-a
- A10 няма да го използваме
- A9 до A8 се подава от Binary Counter-a. Използва се за създаване на комбинация за едно и също число с цел визуализиране на различните цифри от негол
- A7 до A0 се подава от Bus-a. Това е 8 битовото ни число, което е Two's Complement.
- SYM: Това е какъв символ се очаква да се визуализира. Може да е   **-**, **0**, **1**, **2**, **3**, **4**, **5**, **6**, **7**,**8**, **9** или никакъв (**X**). Таблицата по-долу показва кои пинове трябва да се активират на 7 Segment Display за да се визуализира такова число/знак
- EEPROM I/O - Display Pin таблица ни показва как трябва да са свързани изходите на EEPROM-a за да може сложените стойности в него да активират правилните пинове.

| SYM  | Pin 7 | Pin 6 | Pin 5 | Pin 4 | Pin 3 | Pin 2 | Pin 1 |
| ---- | --- | --- | --- | --- | --- | --- | --- |
| `X`  | *LOW* | *LOW* | *LOW* | *LOW* | *LOW* | *LOW* | *LOW* |
| `-`  | *LOW* | *LOW* | *LOW* | *LOW* | *LOW* | *LOW* | **HIGH** |
| `0`  | **HIGH** | **HIGH** | **HIGH** | **HIGH** | **HIGH** | **HIGH** | *LOW* |
| `1`  | **HIGH** | *LOW* | *LOW* | **HIGH** | *LOW* | *LOW* | *LOW* |
| `2`  | *LOW* | **HIGH** | **HIGH** | **HIGH** | **HIGH** | LOW | **HIGH** |
| `3`  | **HIGH** | **HIGH** | *LOW* | **HIGH** | **HIGH** | *LOW* | **HIGH** |
| `4`  | **HIGH** | *LOW* | *LOW* | **HIGH** | *LOW* | **HIGH** | **HIGH** |
| `5`  | **HIGH** | **HIGH** | LOW | LOW | **HIGH** | **HIGH** | **HIGH** |
| `6`  | **HIGH** | **HIGH** | **HIGH** | LOW | **HIGH** | **HIGH** | **HIGH** |
| `7`  | **HIGH** | *LOW* | *LOW* | **HIGH** | **HIGH** | *LOW* | *LOW* |
| `8`  | **HIGH** | **HIGH** | **HIGH** | **HIGH** | **HIGH** | **HIGH** | **HIGH** |
| `9`  | **HIGH** | *LOW* | *LOW* | **HIGH** | **HIGH** | **HIGH** | **HIGH** |

| EEPROM I/O | Display Pin |
| --- | --- |
| I/O 0 | Pin 1 |
| I/O 1 | Pin 2 |
| I/O 2 | Pin 3 |
| I/O 3 | Pin 4 |
| I/O 4 | Pin 5 |
| I/O 5 | Pin 6 |
| I/O 6 | Pin 7 |
| I/O 7 | |

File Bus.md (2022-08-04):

# Bus:

- Поточната линия по която се трансферира информация между компонентите в компютъра
- Модул слага данните си на бус линията и така друг модул може да ги прочете

**Load** - Ще сложи информацията от буса на регистъра

**Enable** - Ще сложи информацията от регистъра на буса.

**Clock** - Ще извърши **Load** или **Enable** операцията. Така мога само със един сигнал да извърша избраната операция.

- Съответно първо трябва да изберем, каква операция искаме да извършим на даден регистър и на следващият Clock Cycle тя ще бъде извършена.
- С тази разбивка на операциите на регистъра, може да си запазим информацията в регистър и да оперираме с друг без да объркаме останалите.



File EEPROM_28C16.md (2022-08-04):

# EEPROM Atmel 28C16

- 16K памет като 2048 думи по 8 бита. 
  - (16K = 16000 Bits / 2000 Bytes /  1.953125 Kilobytes) 
  - Дължината на един DWORD е 8 бита.
  - Съответно имаме 16000 / 8 = ~2000 реда/адреса

- Non-volatile - Енергонезависима - И след изключването ще пази информацията

| Pin Name | Function |
| --- | --- |
| A0 - A10 | Addresses |
| CE (Active Low) | Chip Enable |
| OE (Active Low) | Output Enable |
| WE (Active Low) | Write Enable |
| I/O 0 - I/O 7 | Data Inputs/Outputs |

- **Active Low** -> Трябва да е свързан към **GROUND** за да бъде **активирано** дадено нещо.

- **Изхода** и **входа** са на **едни и същи пинове**. Определяме тези пинове **кое от двете състояния ще бъдат**, **чрез** **OE** и **WE** **пиновете**

READ:

- CE - LOW (Активиран е чипа)
- OE - LOW (Включено е в режим изход)
- WE - HIGH (Изключен е режима за писане)
- След слагането на пиновете в тези състояния според това какъв адрес сме подали на A0 - A10 ще получим данните от адреса на I/O0-I/O7 пиновете.



| Symbol | Parameter | Time |
| --- | --- | --- |
| tACC | Address to Output **Delay** | ? - 150 ns |
| tCE | CE to Output **Delay** | ? - 150 ns |
| tOE | OE to Output **Delay** | 10 - 70 ns |
| tDF | CE or OE High **to Output** Float | 0 - 50 ns  |
| tOH | Output Hold from OE,CE or Address, whichever occurred first | |

- Тук нямаме никакви пулсове.

WRITE:

- WE - LOW (Включваме режим писане) 
  - Пулс
- OE - HIGH (Изключен е режим изход)
- CE - LOW (Активиран е чипа)

- Адреса се вкарва на falling edge на WE пулса. (Аз го разбирам веднага щом от HIGH сменим на LOW за определеното време, защото тогава имаме falling edge, което е прехода от HIGH -> LOW)
- Данните се вкарват на rising edge на WE пуслса. (Значи когато вече се връща от LOW -> HIGH)

- Ако не е нужно при вкарването на данните да седи селектиран адреса, защото двете се запазват в чипа отделно, мога да преизползвам пинове. (Не съм сигурен.)
- 

# EEPROM Programmer:

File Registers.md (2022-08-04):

# Registers:

- Повечето **CPU**-та имат **регистри**
- Регистрите запазват **малко количество информация**
- Информация, която се **обработва от процесора**

Във нашият **8-bit** компютър ще имаме **3 бр. регистри**, като **всеки един от тях ще е с големина 8 bit-a**

- Регистри:
- - A - Генерален. Ще го използваме да запазваме каквато и да е информация без конкретно предназначение
  - B - Генерален. Ще го използваме да запазваме каквато и да е информация без конкретно предназначение
  - IR - Instruction Register. Ще го използваме за сегашната инструкция, която се извършва

- Регистрите имат 3 линии за контрол:

  | Операция | Какво прави?                                 |
  | -------- | -------------------------------------------- |
  | Load     | Запазва битовете от входа към регистъра      |
  | Enable   | Изкарва битовете от регистъра към изхода     |
  | Clock    | Извършва избраната операция Load или Enable. |

- Ако искаме да реализираме наш регистър:

- - Може да използваме **D-Flip-Flop**. Той покрива запазването на бит при **Rising Edge** на **Clock** сигнала. (**D Flip Flop.md**)
  - За да постигнем цялото това нещо, трябва да разширим D-Flip-Flop-a, така че да приема данни и запазва, само когато имаме LOAD.
  - **! На снимката EN трябва да е LOAD. Просто съм го объркал ..**.

  

  - **Сега изниква друг проблем.** 
  - - Нека запазим 1-ца в регистъра. **LOAD (1)**, **D(1)** и **CLK(1)**
    - След нека извършим следните операции - **EN (0)**, **D(0)** и **CLK(1)**, като това ще разруши нашата запазена 1-ца. 
    - Това се получава, защото при **Inverter-a** от **D сигнала** винаги **имаме HIGH** сигнал
  - Едно решение, което ми изникна беше да сложа **AND GATE** между **CLK** и **LOAD** сигнала.
  - - В крайна сметка след четене из коментарите не намирих добро обяснение, защо това не е добра идея да се използва. Опитах се да разбера как това ще доведе до проблем, но не измислих нищо. Ще го реализирам с Feedback за да видя друг начин за решаване на проблем, който така и не намерих, защото е проблем.
  - Използвах идеята сигнала от **Q** да бъде доставен до **D**, ако няма **LOAD**. Така дори и да се тригърне **CLK**, то ще продължим да пазим същата стойност.
  - 
  - 

- За сега имаме просто един **D Flip Flop** със **Enable** логика

### Ако искаме да свържем регистъра ни към бус лентата:

- Ще имаме проблем, защото постоянно ще изкарва изхода си на буса.
- Ще трябва по някакъв начин да казваме дали стойноста в регистъра да се изкарва на буса. **(Enable)**
- Едно решение, което би ни хрумнало е да свържем резултата на регистъра с **AND** и **Enable**-a. Това ще доведе до проблем, защото ако AND изкарва 0, то ще дърпа Current-a (Sink) и така ако друг регистър иска да изкара 1, то 1-цата ще бъде "засмукана" от регистъра, който изкарва 0 и няма да стигне по-надолу.
- Друг вариант е да имаме нещо, което може да подава сигнал (1, Source), да взима сигна (0, Sink) и да не е свързано към веригата (Z). Това ще ни го свърши Tri-state Buffer-a. 



- Два 1-битови регистри:



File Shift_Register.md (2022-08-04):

# Shift Register:

- SN74HC595N

- Shift Register (SN74HC595N) е от типа SIPO.
- SIPO - Serial In - Parallel Out:
  - Запазването на информацията в Shift Register-a става последователно (SIPO). Има и такива, при които е паралелно (PISO).
  - Извличането на запаената информация от Shift Register-а става наведнъж (SIPO). Има и такива, при които е последователно (PISO).

- Отдолу SIPO Shift Register-а е реализиран с няколко JK Flip Flop-a:



- Когато се подготви бит (DATA) и се вкара с Clock-a (CLK), то другите се изместват нагоре.
- Така може да подготвим множество данни, които да ги изкараме наведнъж.
- Примерно, ако използваме Arduino и не ни стигат пиновете да контролираме нещо, което иска да получи данните наведнъж на всичките си пинове, то може да ги подготвим в Shift Register.
- Тоест Shift Register-a ни се явява и като Converter между Serial и Parallel Communication.

### Връщаме се на SN74HC595N:

| Pin | State | Description |
| --- | --- | --- |
| Q0-Q7 | Output | Това са пиновете с резултатите от Shift Register-a. Може да са в Hi-Z / 3-State състояние, ако OE е LOW - тоест изключение. |
| DS / SER | Input | Бита, който ще бъде запазен при Rising Edge-a на SRCLK |
| OE | Active Low  | Дали да се изкарват данните от Shift Register-a на Q0 - Q7, ако ли не то тези пинове са в Hi-Z / 3-State състояние. |
| ST_CP / RCLK | Active High | Най-вероятно има два Storage-а вътре. Shift Register и Storage Register. Първо запазваме данните в Shift Register чрез DS / SER & SH_CP / SRCLK и след това подаваме пулс тук и те се местят в Storage Register, като тогава вече може да ги изкраме на изхода чрез OE. |
| SH_CP  / SRCLK | Active High | Запазва бита Rising Edge-а на подадения сигнал , който е подготвен на DS / SER пина. |
| MR / SRCLR | Active Low  | Изчиства данните от регистъра. |

- Active High - Трябва да е подаден ток за да се изпълни действието, което извършва пина.
- Active Low - Трябва да НЕ е подаден ток за да се изпълни действието, което извършва пина.

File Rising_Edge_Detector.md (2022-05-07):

- Идеята на **Rising Edge Detector**-a е да **прихване** електрическият сигнал, когато **започва да нараства**.

- Един вид само част от него в началото на пускането му/появата.



*(На снимката е примерна черта за нарастването. Може и да е много по-плавна, зависи колко сме приближили.)*

- Всеки един електрически сигнал от 0 до X волта има време докато достигне X волта
- Всеки един електрически сигнал от X до 0 волта има време докато спадне до 0 лота

- С Edge Detector-a може да хванем само част от сигнала, когато той се появи. Казваме му Edge, защото хваща много малка част от сигнала, когато той едва още не е достигнал X волта. Реално частта на нарастването му.

# Един начин за постигането на цялото това нещо:



| S | E |
| ---- | --- |
| 0 | 0 |
| 1 | **1 за определено време** |
| 1 | **0 след определеното време на 1** |

- (**1 за определено време**) Определеното време зависи колко време ще бъде забавен сигнала от Inverter-ите при смяната на **S** от **0** към **1**
- (**0 след определеното време на 1**) След като изтече времето на **1** при смяната на **S** от **0** към **1**, то вече имаме **0** на **E** дори и на **S** да остане **1**

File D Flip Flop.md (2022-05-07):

# D Flip Flop

- Представлява D Latch, който бива активиран от Clock вместо директно от бутон.
- При Clock-a отново имаме подаване на сигнал, но е само един път за да сложим състоянието на Set/Reset-a.



| D Latch | D Flip Flop |
| --- | --- |
| 1. Задържаме EN бутона. <br>2. Задържаме/Отпускаме D бутона за да изберем състояние на Latch-a.<br>3. Отпускаме EN бутона, докато все още сме задържали/отпуснали D бутона за да сложим състоянието.<br> | 1. Задържаме/Отпускаме D бутона за да изберем състояние на Latch-a.<br>2. Натискаме CLK бутона докато сме задържали/отпуснали D бутона за да сложим състоянието. |
| Има нужда Enable логиката (EN) да бъде задържана за да може да се променя състоянието. Трябва да бъде задържана, след това избрано състояние и после отпусната без да се отпуска D. | Няма нужда Enable логиката (CLK) да бъда задържана за да може да се променя състоянието. Нужно е само един път да се натисне и се слага мигновенно състоянието. |
| Ако оставим Enable логиката може да променяме състоянието. | Дори и да оставим Enable логиката натисната няма повече да се промени състоянието. Това става мигновенно при първоначалното натискане. |

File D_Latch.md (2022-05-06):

### Тест 1: (Enable Logic Only without SR Latch)

- Идеята на Enable e че натискаме бутон EN, който позволява бутон D да работи.
- D бутона в конкретният тест активира или Output 1 (O1) или Output 2 (O2).



| D | EN | Output 1 | Output 2 |
| ---- | ---- | --- | --- |
| 0 | 0 | 0 | 0 |
| 0 | 1 | 1 | 0 |
| 1 | 0 | 0 | 0 |
| 1 | 1 | 0 | 1 |

### Тест 2: (Целият D-Latch)

### 



| EN | D | Ouput 1 | Output 2 | Output 3 | Output 4 |
| ---- | ---- | --- | --- | --- | --- |
| 0 | 0 | 0 | 0 | Output 3 | Output 4 |
| 1 | 0 | 1 | 0 | 1 | 0 |
| 0 | 1 | 0 | 0 | Output 3 | Output 4 |
| 1 | 1 | 0 | 1 | 1 | 0 |

Базиране е таблицата върху **Hold EN** -> **Hold/Realese D** -> **Realese EN**.



- При **Hold** на **EN**-a, то *винаги* отиваме в това състояние:

$$
O_3 = 1 \\
O_4 = 0
$$

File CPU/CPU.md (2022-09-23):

Контролни сигнали:

- CA - (Това ознчава, че даденият сигнал се изпълнява, когато дойде Clock пулса. Също така това означава, че даденият сигнал трябва да е активен преди да е дошъл Clock Pulse-a)
- TODO: Да видя кои са зависими от Clock Pulse-a и да си ги маркирам.

1. **Clock:**
   - **HALT** (Спира Clock-a, **Halt**)

2. **A Register:**
   - **CLR** (Изтрива записаната стойност в регистъра, **Clear**)
   - **AO** (Пуска сегашно запазената стойност от регистъра на Bus-a, **A Register Output**)
   - **AI** (Запазва стойността, която в момента се намира на Bus-a, **A Register In**, *Active Low*)
3. **B Register:**
   - **CLR** (Изтрива записаната стойност в регистъра, **Clear**)
   - **BO** (Пуска сегашно запазената стойност от регистъра на Bus-a, **B Register Output**)
   - **BI** (Запазва стойността, която в момента се намира на Bus-a, **B Register In**, *Active Low*)
4. **Instruction Register:**
   - **CLR** (Изтрива записаната стойност в регистъра, **Clear**)
   - **IO** (Пуска сегашно запазената стойност от регистъра на Bus-a, **I Register Output**)
   - **II** (Запазва стоността, която в момента се намира на Bus-a, **I Register In**, *Active Low*)

5. **Flags Register:**
   - *Все още не съм го направил!*

6. **ALU:**

   - **EO** (Пуска сегашно записната/пресметната стойност от регистъра на Bus-a, **Enable Output**)
     - При мен мисля, че не е Active Low, защото съм го позиционирал по друг начин

   - **SU** (Изважда стойностите, който са му подадени от регистър A & B, **Subtract**)

7. **RAM:**
   - **PROG** (Сменя между това дали адреса и данните ще идват от Bus-a или от ръчно от DIP Switch-овете, **Program**)
   - **CLR** (Изчиства записаната стойност от регистъра за адреса, **Clear**)
   - **MI** (Дали да се запази избраният адрес,**Memory Address Register In**, *Active Low*)
   - **RO** (Пуска сегашно избраната стойност от адреса в паметта на Bus-a, Ram Output)
     - При мен мисля, че не е Active Low, защото съм го позиционирал по друг начин
   - **RI** (Запазва сегашно избраната стойност на избраният адрес в паметта, **Ram In**)

8. **Program Counter:**
   - **R** (Рестартира брояча, **Reset**, Active Low)
   - **CE** (Паузира брояча. Това е свързка между два сигнала, които ако са HIGH брояча е пуснат, а ако са LOW е паузиран, **Counter Enable**)
   - **J** (Зарежда стойноста от буса в брояча, Как ще го използваме за Jump-a, **Jump**, Active Low)
   - **CO** (Изкарва изброената стойност на буса, **Counter Out**)
     - При мен мисля, че не е Active Low, защото съм го позиционирам по друг начин)

9. **Output Register:**
   - **OI** (Зарежда стойноста от буса в дисплея, **Output In**)

LDA 14 (Зареди данните от 14 адрес от паметта в регистър A)

ADD 15 (Зареди данните от 15 адрес от паметта в регистър A)

OUT

- Ние решаваме как да си кръстим командите, защото ние правим компютъра
- Всяка една команда е запазена в паметта:

LDA 14:

- 0000 адрес
- 0001 1110 данни, където 0001 репрезентира LDA командата, а 1110 репрезентира 14, което е адреса от който искаме да заредим

ADD 15:

- 0001 адрес
- 0010 1111 данни, където 0010 репрезентира ADD командата, а 1111 репрезентира 15, което е адреса от който искаме да заредим

OUT:

- 0010 адрес
- 1110 0000 данни, където 1110 репрезенитира OUT командата, а 0000 нищо.

LDA (Зареди данните от X адрес от паметта в X регистър)

- TODO: Следва да гледам и разписва идеята за контролната логика

- Всичките контролни сигнали ще ги свържа на един Breadboard. Идеята е лесно да контролирам целият компютър от едно място на ръка.

- Някой от контролните сигнали, който са Active Low ще ги обърна.
- Колко още Breadboard-a ще ми трябват, защото на някой места той слага счупени и така има за буса, а аз не ги чупя.



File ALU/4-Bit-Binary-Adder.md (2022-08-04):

- Приемаме, че **вече сме запознати** как работи операцията събиране при бинарни числа.
- ! Като цяло алгоритъма за сибиране на числа при дадена основа (**2**,**8**,**10** ...) е един и същ.
- Долу съм оставил записките си, който ми помогнаха да намеря начин за постигането на верига, която ще пресметне **две бинарни числа**, но и същевременно може да работи с carry битове.







- Сега ако комбинираме 1 bit adder-a ни, може да си направим такъв и за по-големи числа.



- Имаме и вече готови 4-bit-ови Adder-и като **74LS283**:
- 74ls283-pinout

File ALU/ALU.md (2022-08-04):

# ALU: (Arithmetic Logic Unit)

- **Изчислителният модул** на нашият компютър ни дава възможноста да извършваме **операции** **върху две** **8-битови** числа
- **Операциите**, които можем да извършваме са **събиране** и **изваждане**
- Начина по който това става:
- - 1. **Стойностите** на **A** и **B** **регистъра** се **подават** на **изчислителният модул** (ALU)
    2. Стойноста на **B** регистъра минава през **Two's Complement** логика преди да достигне до събирача. Това се прави заради операция изваждане. Ако сме избрали изваждане, то стойноста на B регистъра се обръща в такава преди да достигне събирача, която стойност събрана с положително число ще го извади.
    3. Имаме **два** **4 битови събирача**, които са **свързани един с друг** за **да направят 8 битов събирач**.
    4. **Резултата** ни от **8 битовия събирач минава през tri-state** за да **може да бъде свързан с бус лентата**.

- Как работи събирането на две бинарни числа може да се види в **4-Bit-Binary-Adder.md**
- Как работи събиране на положително с "отрицателно" може да се види в **Negative-Numbers.md**

- **Комбиниране** на **два** **4** битови събирача **за да получим 8 битов** такъв:

  

- Залагане на **tri-state** за да **може да го свържем към бус лентата**.

  

- Добавяне на логиката за изваждане:



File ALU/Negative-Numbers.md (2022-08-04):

# Negative Numbers in Binarry:

- Как се представят отрицателните бинарни числа?
- Събиране на отрицателни бинарни числа?

- Запознати сме вече как се представят десетични числа в бинарен вид.

- Запознати сме вече как се събират две положителни бинарни числа.

- Има само един приет начин за репрезентиране на отрицателни бинарни числа, който ни позволява да извършваме операцията събиране безпроблемно. Този начин се нарича **Two's Complement**. (Допълнение с две)

### Начало:

- Ако искаме да знаем дали едно бинарно число е положително или отрицателно може да резервираме един бит за това.

- Прието е това да е първият:

- - 1 -> Отрицателно
  - 0 -> Положително

- Следващите битове репрезентират числото.

- **Важно е да отбележим, че трябва да знаем с колко битови числа работим.** В примерите с 4 битови. Така знаем на коя позиция се намира Sign Bit-a.

  

- Нека проверим как работи събирането, когато имаме отрицателно при този метод:



- Видимо не получаваме правилен резутат според таблицата по-горе.
- Ще направим опит да намерим няколко отрицателни числа, които удволетворяват нашите изисквания.
- 

- Ако искаме да обърнем дадено число в отрицателно, просто обърщаме битовете и добавяме едно:





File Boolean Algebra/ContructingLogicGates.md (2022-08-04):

# Конструиране на Logic Gate-ове:

- Имаме случай, когато трябва да постигнем някаква дигитална логика.

- Съответно в тези случай просто може да си направим една булева таблица на това, което искаме да постигнем.
- Остава обаче въпроса, как може да сътворим електрическата верига, която да постигне очакваният от нас резултат?

1. **Изкарваме си булевата таблица на това, което искаме да постигнем.**
2. **Създаваме булевият израз от булевата таблица.** (Skip Logism) (Автоматично опростява)
3. **Опростяваме създаденият булевият израз** (Skip Logism)
4. **Конструираме електрическата верига**

##### **Task 1**: Искаме да постигнем дигитален Switch, който да пропуска сигнали от A или B в зависимост от избора ни:



1. **Изкарваме си булевата таблица на това, което искаме да постигнем:**

| S (Select) | A | B | O |
| --- | ---- | ---- | ---- |
| 0 | 0 | 0 | 0 |
| 0 | 0 | 1 | 0 |
| 0 | 1 | 0 | 1 |
| 0 | 1 | 1 | 1 |
| 1 | 0 | 0 | 0 |
| 1 | 0 | 1 | 1 |
| 1 | 1 | 0 | 0 |
| 1 | 1 | 1 | 1 |

2. **Създаваме булевият израз от булевата таблица:**

- За всеки един ред, където **O** = **1 ** изписваме булевият израз, който го съставя:
  $$
  \\ \bar{S}.A.\bar{B}
  \\ \bar{S}.A.B
  \\ S.\bar{A}.B
  \\ S.A.B
  $$

- Сега това вече може да го обърнем в един булев израз:

$$
\\ \bar{S}.A.\bar{B} +
\bar{S}.A.B +
S.\bar{A}.B + 
S.A.B =
O
$$

3. **Опростяваме създаденият булевият израз**

- Може да го видим в **Simplification.md** как става. 
- Изразите генерирани от такива таблици следват една и съща идея и метода по опростяването им е почти еднакво

3. **Конструираме електрическата верига**

- Ние си го правим, което е просто ако сме си опростили булевият израз
- Използваме Logism, като там директно може да подадем израза или просто да попълним таблица, което елиминира **2** и **3** стъпка

**Не опростена:**



**Опростена:**



**Links:**

- https://www.allaboutcircuits.com/textbook/digital/chpt-7/converting-truth-tables-boolean-expressions/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

- https://www.ilovefreesoftware.com/16/tutorial/how-to-convert-boolean-expression-to-logic-circuit.html
- https://www.allaboutcircuits.com/textbook/digital/chpt-7/boolean-rules-for-simplification/
- https://www.boolean-algebra.com/

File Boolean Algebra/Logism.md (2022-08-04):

# Logism:

- Много добра програма за създаване на елктрически схеми от логически елементи според израз или таблица

1. **Създаване на електрическа схема за булева таблица:**

- Ако приемем, че имаме следната булева таблица:

| S (Select) | A | B | O |
| --- | ---- | ---- | ---- |
| 0 | 0 | 0 | 0 |
| 0 | 0 | 1 | 0 |
| 0 | 1 | 0 | 1 |
| 0 | 1 | 1 | 1 |
| 1 | 0 | 0 | 0 |
| 1 | 0 | 1 | 1 |
| 1 | 1 | 0 | 0 |
| 1 | 1 | 1 | 1 |

- Отиваме при **Window** -> **Combinational Analysis**
- **Inputs** добавяме всичките входове - **S**, **A** и **B**
- **Outputs** добавяме всичките изходи - **O**
- **Table** попълваме с кликане върху всеки ред за **O**, какво очакваме при комбинацията от **S**, **A** и **B**



- **Build Circuit** и сме готови.
- [**Note**] Чрез този метод автоматично получаваме булевият израз (опростен) в **Expression**



2. **Създаване на електрическа схема за булев израз:**

- Ако прием, че имаме следният булев израз:

- $$
  \\ \bar{S}.A.\bar{B} +
  \bar{S}.A.B +
  S.\bar{A}.B + 
  S.A.B =
  O
  $$

- [**Note**] Създаден е от горната булева таблица, **но не е опростен**.

- Отиваме при **Window** -> **Combinational Analysis**

- **Inputs** добавяме всичките входове - **S**, **A** и **B**

- **Outputs** добавяме всичките изходи - **O**

- **Expression** попълваме булевият, даваме **Enter ** и **Build Circuit**:

- `~S A ~B + ~S A B + S ~A B + S A B`





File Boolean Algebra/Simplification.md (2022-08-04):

`+` = OR

`.` = AND



- A.A = A, защото A е една и съща стойност.
- - Тоест е променлива, която няма едновременно как да има две различни стойности
  - `A = 1, 1.1 = 1`. `A = 0, 0.0 = 0`

- A.0 = 0, защото `.` репрезентира AND, съответно 0 със каквото и да е било при AND Gate ще даде 0-ла.



- Изглежда най-добрият вариант са такива създадени от таблица е да използваме директно Distributive и после елиминиране.

- Сходната логика за такива изрази от таблица се получава защото винаги генерираме в един и същи формат:

- - X..**r** + n
  -  **r** са колоните от таблицата взети за генерирането на изразите съставящи Output-a
  - n са редовете от таблицата взети за генерирането на изразите, където изхода е 1

  - Примерно ако сме имали таблица с 3 входа (A, B, C), и 5 реда, където имаме 1-ца:
  - - ABC + ABC + ABC + ABC + ABC, като само не знаем къде имам обърнати стойности на A, B или C, съставящи дадената 1-ца

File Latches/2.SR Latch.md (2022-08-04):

# SR Latch:

- SR Latch е акроним на **Set-Reset Latch**
- То е **Multivibrator** от тип **Bistable**
- Реализира се със **два** **NOR Gate**, които са **свързани взаимно**.



> S -> Q
>
> R -> Q Inverted

**SR Latch** в [CircuitJS](https://www.falstad.com/circuit/circuitjs.html):

- Чрез експериментиране може да видим какво се случва във веригата
- Файл: **/CircuitJS/sr_latch.circuitjs.txt**



- Приемаме, че **Reset (R)** е отгоре, а **Set (S)** е отдолу, съответно **Q** е отгоре, а **Q Inverted** отдолу.
- Ако **Reset (R)** и **Set (S)** са **On** едновременно, то имаме **невалидно състояние**.
- Ако след избирането на състояние чрез **подаване** на **Reset (R)** или **Set (S)** **премахнем** подаденото състояние, то **остава**. (*От тук идва смисъла на Latch-a*). Това **също означава**, че **сегашното състояние** на **Q** или **Q Inverted** е последното избрано от **Reset (R)** или **Set (S)**

- Състоянието в което ще стартира е винаги на случаен принцип, защото според променливи фактори единият сигнал ще достигне по-бързо от другият.
- Друго обяснение на [Race Condition](https://electronics.stackexchange.com/questions/155949/what-is-race-condition-in-flip-flops)



- След като SR Latch-a е стартирал в дадено състояние, то ще го пази.

- Не се губи, защото постоянно се подава м/у NOR Gate-овете.

- Като променяме входа на **Reset (R)** и **Set (S)** можем да променим състоянието на **SR Latch** */* **Q** и **Q Inverted**

  | Reset (R) | Set (S) | Q    | Q Inverted |
  | --------- | ------- | ---- | ---------- |
  | 0         | 0       | Q    | Q          |
  | 0         | 1       | 1    | 0          |
  | 1         | 0       | 0    | 1          |
  | 1         | 1       | 0    | 0          |

- Като стойности са сложени **Q** или **Q Inverted**, защото или получава същата стойност или обратната.

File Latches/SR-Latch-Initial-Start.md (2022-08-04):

# Set-Reset Latch Initial Start Problem:

- Докато правех регистрите имах проблем с SR Latch-a.

- Това, което се получаваше в CircuitJS беше:

- - Постоянно държеше и двете състояния пуснати
  - Не можеше да стартира в стабилно състояние, без значение кое



- Колкото и пъти да давах Reset на симулацията това нещо продължаваше да се появява дори и SR Latch-a да е откачен от всякъде.
- Затова реших да намеря начин винаги да я стартирам в избрано състояние за да избегна този проблем.

1. Искам отново да може да бъде свързана към нещо и то да я контролира, но и същевременно при пускането на веригата да стартира в това състояние.
2. Съответно ми трябва нещо, което да подаде ток замалко при пускането на веригата и повече да не подава после:



- Същият механизъм за хващане на Rising Edge ми върши перфектна работа. В началото на пускането на веригата ще хване Rising Edge-a и ще подаде моментен сигнал към входа на SR Latch-a. 
- **! Както знаем, не е нужно постоянно да подаваме сигнал на входа на SR Latch-a за да държим състоянието.**

3. Сега ще ни трябва да свържем първоначално пускащия сигнал за задаването на състоянието на SR Latch-a, както и този за динамичното и контролиране. Трябва обаче и двете неща да са разкачени едно от друго, защото когато имаме Logic Gate с 0 състояние, то той консумира сигнала. 



- Ако използваме Tri-State, то:
- - Долният сигнал за слагане на първоначалното състояние ще мине, защото ще активира и Tri-State-a, след това неговата линия няма да е активна повече - ще бъде разкачена от Tri-State-a
  - Горният сигнал, ако е 1 ще минава, но иначе няма да поглъща сигнала на долната.

В крайна сметка намерих по-лесен вариант:



- Директно при пускането ще имаме ток от другата страна на кондензатора докато не се зареди, което ще ни сложи стабилно състояние на веригата...

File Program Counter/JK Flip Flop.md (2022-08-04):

# JK Flip Flop:

### Какво е JK-Flip-Flop:

- Идеята му е да реши проблема на **SR Latch with Enable**.
- Проблема, който **SR Latch with Enable** има е че ако **S (Set)** и **R (Reset)** са **HIGH** и **EN (Enable)** също е **HIGH**, то резултатите **Q** и **Q Inverted** ще са **LOW**.



- Ако S (Set) и R (Reset) са HIGH, но все още EN (Enable) е LOW:



- Ако искаме сега след като дойде EN (Enable) да нямаме Q и Q Inverted - LOW, то ако сложим AND за да може:
  - R да се активира, ако Q е HIGH
  - S да се активира, ако Q Inverted е HIGH
- Така ще избегнем проблема Q и Q Inverted да са LOW, когагато EN (Enable) е HIGH



- Обаче сега има друг проблем, подава се EN (Enable) - HIGH и S (Set) и R (Reset) - HIGH, когато се сменя състоянието към противоположното, то ще се смени отново обратно и същият този цикъл може да се повтори няколко пъти без да сме сигурни в какво състояние ще завършим.
- Искаме, когато EN (Enable) е HIGH, S (Set) и R (Reset) са HIGH Latch-a да се сменя в противоположното състояние винаги.

### Какво е Master-Slave JK-Flip-Flop:



- Както виждаме наследява 2-та AND-та, които предотвратяват LOW на изходите и пускане само на противоположното.
- Тук обаче имаме SR Latch-a, който играе ролята на посредник (Master) между финалният ни SR Latch (Slave).
- Сега, когато дойде EN (Clock) ни е HIGH, няма все още да сме подали противоположната стойност към финалният SR Latch (Slave).





- Както виждаме тя отива в първият SR Latch (Master), но все още не се пуска към финалният (Slave), защото трябва да отпуснем EN (Clock) за да стане това.
- Така Feedback-a от финалният SR Latch (Slave) не прецаква AND-овете в началото, защото за да стигнат до края и отново да си подадат новият резултат трябва да отпуснем Clock-a, а след като е отпуснат няма да може да приеме новите резултати от Feedback-a и да ги подаде отново.

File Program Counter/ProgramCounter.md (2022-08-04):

# Program Counter:

- Реализираме го чрез 74LS161: 4-bit binary counter.
- В основата си 74LS161 се състои от 4 броя Master-Slave JK Flip Flop-a.

- Приемаме, че сме запознати как **JK Flip Flop** работи.

- Има едно **много интересно нещо**, което се получава, когато с**вържем няколко JK Flip Flop-a заедно**.

- **Свързването им се състой** от това **изхода на единият да е Clock на другият**, а **J** и **K** **винаги да са свързани HIGH**

  

- Трите ни изхода от JK Flip Flop стават бинарен брояч. На всяко едно CLK подадено на първия бинарната стойност на изходите се вдига с 1
- Цялото това нещо се получава, заради посредника на SR Latch (Master) и слагането на състоянието при LOW сигнал на Clock-a.
- Ако започнем от нулата (Всички изходи от JK Flip Flop са 0), то:

1.  Първия JK Flip Flop става HIGH, като това не води до нищо важно все още
2.  Първия JK Flip Flop стана LOW, като това води изхода му да е HIGH, а CLK на втория JK Flip Flop да е HIGH
3.  Първия JK Flip Flop става HIGH, като това не води до нищо важно все още
4.  Първия JK Flip Flop става LOW, като това води изхода му да е LOW, а CLK на втория да е LOW, което активира резултата му и той да стане HIGH

- Целият този цикъл прави изходите да броят с едно на всеки един Clock цикъл, защото ако най-долната стойност стане едно, то всички стойности, който са свързани с пряко с нея и са 1 ще станат 0, а първата след тях ще стане 1:





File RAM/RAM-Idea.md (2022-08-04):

# RAM:

Еднобитовия регистър, който бяхме създали в CircuitJS. Ще го използваме за съхранение на стойност и нейното менажиране:



Еднобитовият регистър, превърнат в чип/subcurcit за CircuitJS за да може да веригата, която ще създадем да изглежда по-чиста:



2 byte ram:



- Два реда, на всеки по 8 броя 1 битови регистри, което води до съхранението на 1 byte на ред
- Също така на редовете, който запазват един byte също им се казва word

- Съответно имаме 2 byte-a рам.
- При следващият Clock сигнал в зависимост коя клетка/ред сме избрали да пишем върху ще запазим 1 byte от данни
- В нашия компютър, ако имаме 16GB памет, това са 16 000 000 000 Byte-a или 16 милиона реда, способни да съхранят 1 byte всеки.
- Ако приемем, че за всеки един бит от ред имаме **примерно** 50 транзистора, който съставят логическите gate-ове и т.н, то на ред отиват 50 * 8 = 400 транзистора. За 16 милиона реда това са 16 000 000 000 * 400 = 640 000 000 000 милиарда транзистора нужни за 16 GB рам.
- **ОБАЧЕ** тук досега показваме и говориме за статична рам SRAM. При динамичната начина на съхранение е по-различен. Там за реализирането на една клетка нямаме сложността като на регистър, а просто един транзистор и кондензатор. Те ни помагат за съхранението на един бит в клетка от ред. Тук обаче ни трябва логика, която редовно да подновява заряда на кондензатора, който ни пази бита. Съответно заради това нещо е по-бавна от статичната, но е по-евтина за изработка заради малкото компоненти, който използва.

Сега ще трябва да можем да си избираме на кой адрес/ред искаме да запазим стойност. (Adress Decoder)

- Да си представим, че имаме 4 byte ram:



- Искаме, чрез битово число да изберем на кой ред ще пишем, а не да имаме връзка към всеки ред и да го избираме:



- Тук A0, A1,A2 репрезентират бинарно число. Имаме им стойностите както оригинални така и обърнати. Имаме и 4 броя AND-ове, като всеки един от тях декодира бинарна стойност. След това в зависимост от декодираната стойност (адрес) проверяваме дали EN или WR операцията е избрана.



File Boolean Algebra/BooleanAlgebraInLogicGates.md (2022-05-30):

# Конструиране на Logic Gate-ове:

- Имаме случай, когато трябва да постигнем някаква дигитална логика.

- Съответно в тези случай просто може да си направим една булева таблица на това, което искаме да постигнем.
- Остава обаче въпроса, как може да сътворим електрическата верига, която да постигне очакваният от нас резултат?

1. **Изкарваме си булевата таблица на това, което искаме да постигнем.**
2. **Създаваме булевият израз от булевата таблица.**
3. **Опростяваме създаденият булевият израз**
4. **Конструираме електрическата верига**

##### **Task 1**: Искаме да постигнем дигитален Switch, който да пропуска сигнали от A или B в зависимост от избора ни:



1. **Изкарваме си булевата таблица на това, което искаме да постигнем:**

| S (Select) | A | B | O |
| --- | ---- | ---- | ---- |
| 0 | 0 | 0 | 0 |
| 0 | 0 | 1 | 0 |
| 0 | 1 | 0 | 1 |
| 0 | 1 | 1 | 1 |
| 1 | 0 | 0 | 0 |
| 1 | 0 | 1 | 1 |
| 1 | 1 | 0 | 0 |
| 1 | 1 | 1 | 1 |

2. **Създаваме булевият израз от булевата таблица:**

- За всеки един ред, където **O** = **1 ** изписваме булевият израз, който го съставя:
  $$
  \\ \bar{S}.A.\bar{B}
  \\ \bar{S}.A.B
  \\ S.\bar{A}.B
  \\ S.A.B
  $$

- Сега това вече може да го обърнем в един булев израз:

$$
\\ \bar{S}.A.\bar{B} +
\bar{S}.A.B +
S.\bar{A}.B + 
S.A.B =
O
$$

- Подготвям Logism:







- `~S A ~B + ~S A B + S ~A B + S A B`

- **Може и директно през Table да си зададем таблицата и да не обърщаме нищо в булеви изрази**

- https://www.allaboutcircuits.com/textbook/digital/chpt-7/converting-truth-tables-boolean-expressions/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
- https://www.ilovefreesoftware.com/16/tutorial/how-to-convert-boolean-expression-to-logic-circuit.html
- https://www.allaboutcircuits.com/textbook/digital/chpt-7/boolean-rules-for-simplification/
- https://www.boolean-algebra.com/

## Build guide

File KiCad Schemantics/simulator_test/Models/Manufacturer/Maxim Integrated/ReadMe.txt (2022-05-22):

SPICE Models

SPICE Macromodel Files

Information furnished by Maxim Integrated Products is believed to be accurate and reliable. However, the company cannot assume responsibility for use of any circuitry other than the circuitry entirely embodied in a Maxim product; nor for any infringements of patents or other rights of third parties that may result from its use. No license is granted by implication or otherwise under any patent rights of Maxim Integrated Products. Maxim reserves the right to change the circuitry and specifications without notice. 

Op-Amp/Comparator Macromodels
Performance parameters incorporated in models are based primarily on measured performance as taken from bench tests and production run averages, and secondarily on split between data sheet MIN/MAX parameter values. Macromodels are intended as an aid for design and prototyping. Industry standard macromodels for op-amps and comparators, including those supplied by Maxim, are based on simplified circuit expressions, and/or replacement of active circuit elements with ideal controlled voltage and current sources. As such, simulation with macromodels should not be relied upon as final proof-of-design. Use of macromodel descriptions is not a substitute for worst-case design analysis, nor for testing real circuits over temperature, supply, and other operating limits.

Op-Amps and Comparators are grouped into families with similar characteristics. These families appear in files named MAXxxx.FAM where MAXxxx is the first part number of the family.

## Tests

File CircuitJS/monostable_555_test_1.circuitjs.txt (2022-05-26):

$ 1 0.000005 58.6985430941709 50 5 50 5e-11
r 784 304 784 352 0 5000
r 784 384 784 432 0 5000
r 784 464 784 512 0 5000
w 784 352 784 384 0
w 864 384 816 384 2
w 864 448 816 448 2
w 784 432 784 448 0
w 784 448 784 464 0
w 784 512 784 528 2
v 640 192 640 224 0 0 40 5 0 0 0.5
w 640 224 640 256 0
w 784 288 784 304 0
w 656 256 640 256 0
g 784 528 784 544 0 0
g 640 192 640 160 0 0
x 795 346 811 349 4 12 R1
x 795 426 811 429 4 12 R2
x 794 506 810 509 4 12 R3
x 591 218 620 221 4 24 5V
x 824 396 857 399 4 12 Reset
x 824 460 842 463 4 12 Set
a 864 464 944 464 9 5 -150 1000000 5 1.6666666666666665 100000
a 864 368 944 368 9 5 0 1000000 3.333333333333333 0.06728855891066589 100000
x 864 317 897 320 4 12 Reset
x 870 512 888 515 4 12 Set
x 849 329 915 332 4 12 Comparator
x 847 523 913 526 4 12 Comparator
w 944 464 976 480 0
x 1053 480 1110 483 4 12 Discharge
w 1072 352 1120 352 0
w 1072 464 1120 464 0
w 944 368 976 336 0
w 960 368 976 368 0
w 960 416 960 368 0
w 1072 416 960 416 0
w 1072 432 1072 416 0
w 944 448 976 448 0
w 1072 464 1072 432 0
w 1072 400 944 400 0
w 1072 384 1072 400 0
w 1072 352 1072 384 0
153 976 464 1072 464 0 2 5 5
153 976 352 1072 352 0 2 0 5
w 944 448 944 400 0
x 980 328 991 331 4 15 R
x 982 474 992 477 4 15 S
x 1054 369 1066 372 4 15 Q
x 1055 456 1067 459 6 15 Q
x 1056 345 1092 348 4 12 Output
g 656 432 656 448 0 0
w 656 432 656 416 0
209 656 384 656 416 0 0.000001 0.06728855891066589 0.001 1
w 272 368 272 352 0
w 272 384 272 368 0
w 656 368 656 384 0
w 272 432 272 448 0
r 272 384 272 432 0 100000
r 656 272 656 304 0 100000
w 272 432 336 432 0
w 816 352 864 352 2
w 272 448 416 448 0
w 816 480 864 480 2
w 816 352 656 352 0
w 816 384 784 384 0
w 816 448 784 448 0
x 626 292 642 295 4 12 R4
x 239 411 255 414 4 12 R5
x 633 429 649 432 4 12 C1
t 1168 512 1184 512 0 1 0.6720010856567563 0.689962530156529 100 default
w 272 368 320 368 0
w 720 320 720 272 0
w 720 272 1072 272 0
r 1120 464 1120 512 0 220
w 1184 496 1184 272 0
w 1168 512 1120 512 0
w 1184 528 1184 544 0
g 1184 544 1184 560 0 0
x 1092 502 1108 505 4 12 R6
x 1176 516 1219 519 4 12 NPN\sT1
s 592 512 592 544 0 1 true
w 656 256 784 256 0
w 784 256 784 288 0
w 656 368 656 352 0
w 544 480 512 480 0
w 512 480 512 256 0
w 512 256 640 256 0
g 592 544 592 560 0 0
r 544 480 592 480 0 5000
w 592 512 592 480 0
r 304 512 304 560 0 1000
w 592 480 816 480 0
w 656 256 656 272 0
w 720 320 656 320 0
w 656 304 656 320 0
w 656 320 656 352 0
r 1072 272 1120 272 0 1000
w 1120 272 1184 272 0
o 29 64 0 4099 0.0000762939453125 0.00009765625 0 2 29 3

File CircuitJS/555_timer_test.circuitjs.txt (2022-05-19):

$ 1 0.000005 382.76258214399064 50 5 50 5e-11
a 864 368 944 368 9 5 0 1000000 3.333333333333333 1.6820510975325085 100000
a 864 464 944 464 9 5 -150 1000000 1.6820510975325085 1.6666666666666665 100000
r 784 304 784 352 0 5000
r 784 384 784 432 0 5000
r 784 464 784 512 0 5000
w 784 352 784 384 0
162 1184 464 1232 464 2 default-led 1 0 0 0.01
t 1200 304 1216 304 0 1 0.6327029621904939 0.6626770121078112 100 default
w 1168 304 1200 304 0
w 864 384 784 384 2
w 864 448 784 448 2
w 784 432 784 448 0
w 784 448 784 464 0
w 1216 336 1216 320 0
w 784 512 784 528 0
v 656 224 656 256 0 0 40 5 0 0 0.5
w 656 256 656 288 0
w 784 288 784 304 0
r 672 320 672 368 0 1000
r 672 400 672 448 0 100000
w 784 288 672 288 0
w 672 288 656 288 0
w 672 448 672 464 0
w 672 320 672 288 0
w 672 464 672 480 0
w 672 480 864 480 2
w 672 464 720 464 0
w 720 464 720 352 0
w 720 352 864 352 2
w 672 384 704 384 0
w 704 384 704 240 0
w 704 240 1152 240 0
w 1216 240 1216 288 0
w 672 400 672 384 0
w 672 384 672 368 0
w 1248 464 1232 464 0
209 672 480 672 512 0 0.000001 1.6820510975325085 0.001 1
w 672 528 672 512 0
153 976 352 1072 352 0 2 0 5
153 976 464 1072 464 0 2 5 5
w 1072 352 1072 384 0
w 1072 384 1072 400 0
w 1072 400 944 400 0
w 944 400 944 432 0
w 1072 464 1072 432 0
w 944 432 944 448 0
w 944 448 976 448 0
w 1072 432 1072 416 0
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

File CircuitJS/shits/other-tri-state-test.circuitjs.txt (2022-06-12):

$ 1 0.000005 10.20027730826997 50 5 43 5e-11
g 368 256 368 240 0 0
v 368 256 368 288 0 0 40 5 0 0 0.5
r 304 288 304 336 0 1600
r 432 288 432 336 0 100
t 400 352 432 352 0 1 -4.251325318698233 0.4903937202898633 100 default
t 400 448 432 448 0 1 2.1892084298147374e-8 0.017315429089372707 100 default
t 272 400 304 400 0 1 -4.464860428311154 0.4903937525057605 100 default
d 432 368 432 416 2 default
w 432 432 432 416 0
w 432 416 464 416 0
r 304 448 304 496 0 1000
g 304 496 304 512 0 0
g 432 464 432 512 0 0
w 432 288 368 288 0
w 368 288 304 288 0
w 304 384 304 336 0
w 304 416 304 448 0
w 400 352 272 352 0
d 240 432 240 464 2 default
d 208 432 208 464 2 default
w 224 464 224 496 0
w 224 464 240 464 0
w 224 464 208 464 0
w 272 400 240 400 0
w 240 400 240 432 0
w 240 400 144 400 0
w 208 432 208 352 0
w 208 352 272 352 0
I 176 496 224 496 0 0.5 5
v 16 400 32 400 0 0 40 5 0 0 0.5
g 16 400 0 400 0 0
w 96 400 112 400 0
s 112 400 144 400 0 1 false
s 144 496 176 496 0 1 false
w 128 496 144 496 0
g 80 496 64 496 0 0
v 80 496 96 496 0 0 40 5 0 0 0.5
x 112 376 149 379 4 24 BIT
x 145 470 178 473 4 24 EN
w 400 448 304 448 0
r 528 448 528 480 0 1000
g 528 480 528 496 0 0
w 528 448 528 416 0
w 528 416 464 416 2
w 528 416 528 320 0
r 32 400 96 400 0 220
r 96 496 128 496 0 220
j 480 656 528 656 32 -4 0.00125
j 480 768 528 768 33 -4 0.00125
v 528 560 528 592 0 0 40 5 0 0 0.5
g 528 560 528 544 0 0
w 528 592 528 640 0
j 480 704 528 704 32 -4 0.00125
j 480 816 528 816 33 -4 0.00125
w 528 688 528 672 0
w 528 800 528 784 0
w 592 736 528 736 2
w 528 736 528 720 0
w 528 736 528 752 0
w 480 704 480 720 0
w 480 768 480 736 0
w 480 720 480 736 0
w 480 736 432 736 0
I 416 816 464 816 0 0.5 5
w 464 816 480 816 0
w 480 656 416 656 0
w 416 656 416 816 0
w 432 736 400 736 0
w 416 816 400 816 0
g 528 832 528 848 0 0
v 336 736 352 736 0 0 40 5 0 0 0.5
g 336 736 320 736 0 0
w 352 736 368 736 0
s 368 736 400 736 0 1 false
s 368 816 400 816 0 1 false
w 352 816 368 816 0
g 336 816 320 816 0 0
v 336 816 352 816 0 0 40 5 0 0 0.5

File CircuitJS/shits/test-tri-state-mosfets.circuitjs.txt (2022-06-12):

$ 1 0.000005 10.20027730826997 50 5 50 5e-11
f 704 400 736 400 33 1.5 0.02
f 672 480 736 480 33 1.5 0.06
f 704 656 736 656 32 1.5 0.02
f 672 576 736 576 32 1.5 0.02
w 736 528 896 528 2
w 736 560 736 528 0
w 736 528 736 496 0
w 704 400 656 400 0
w 656 400 656 656 0
w 672 576 672 480 0
w 672 480 640 480 0
w 736 464 736 416 0
w 736 592 736 640 0
w 736 384 736 352 0
g 736 672 736 688 0 0
v 736 320 736 352 0 0 40 5 0 0 0.5
g 736 320 736 304 0 0
x 748 519 798 522 4 24 OUT
v 288 816 288 768 0 0 40 5 0 0 0.5
f 592 672 624 672 33 1.5 0.02
f 560 752 624 752 33 1.5 0.02
f 592 928 624 928 32 1.5 0.02
f 560 848 624 848 32 1.5 0.02
w 624 800 784 800 2
w 624 832 624 800 0
w 624 800 624 768 0
w 592 672 544 672 0
w 544 672 544 928 0
w 560 848 560 752 0
w 560 752 528 752 0
s 304 752 336 752 0 1 false
w 304 752 288 752 0
w 624 736 624 688 0
w 624 864 624 912 0
w 624 656 624 624 0
x 416 621 440 624 4 24 IN
x 306 725 339 728 4 24 EN
g 624 944 624 960 0 0
w 288 752 288 768 0
v 624 592 624 624 0 0 40 5 0 0 0.5
g 288 816 288 832 0 0
g 624 592 624 576 0 0
x 636 791 686 794 4 24 OUT
w 480 752 336 752 0
f 448 944 512 944 33 1.5 0.02
f 448 1024 512 1024 33 1.5 0.02
f 480 1200 512 1200 32 1.5 0.02
f 448 1120 512 1120 32 1.5 0.02
w 512 1072 672 1072 2
w 512 1104 512 1072 0
w 512 1072 512 1040 0
w 448 944 432 944 0
w 432 944 432 1200 0
w 448 1120 448 1024 0
w 448 1024 416 1024 0
w 512 1008 512 960 0
w 512 1136 512 1184 0
w 512 928 512 896 0
g 512 1216 512 1232 0 0
v 512 864 512 896 0 0 40 5 0 0 0.5
g 512 864 512 848 0 0
x 524 1063 574 1066 4 24 OUT
w 896 528 784 800 0
w 784 800 672 1072 0
w 672 1072 672 1312 0
g 672 1344 672 1360 0 0
r 672 1312 672 1344 0 1000
w 784 800 992 864 0
g 992 896 992 912 0 0
152 992 880 1088 880 0 2 0 5
w 1088 880 1200 880 2
v 336 624 336 656 0 0 40 5 0 0 0.5
g 336 624 336 608 0 0
s 352 656 384 656 0 1 false
w 528 672 544 672 0
w 336 656 352 656 0
w 384 656 448 656 0
w 496 384 640 400 0
w 448 384 464 384 0
s 464 384 496 384 0 0 false
g 448 352 448 336 0 0
v 448 352 448 384 0 0 40 5 0 0 0.5
I 656 656 704 656 0 0.5 5
w 592 480 448 480 0
g 400 544 400 560 0 0
w 400 480 400 496 0
x 418 453 451 456 4 24 EN
x 528 349 552 352 4 24 IN
w 416 480 400 480 0
s 416 480 448 480 0 0 false
v 400 544 400 496 0 0 40 5 0 0 0.5
w 656 400 640 400 0
w 256 1024 368 1024 0
w 272 928 416 944 0
w 224 928 240 928 0
s 240 928 272 928 0 1 false
g 224 896 224 880 0 0
v 224 896 224 928 0 0 40 5 0 0 0.5
w 256 1024 224 1024 0
g 176 1088 176 1104 0 0
w 176 1024 176 1040 0
x 194 997 227 1000 4 24 EN
x 244 904 268 907 4 24 IN
w 192 1024 176 1024 0
s 192 1024 224 1024 0 1 false
v 176 1088 176 1040 0 0 40 5 0 0 0.5
w 416 944 432 944 0
w 448 656 528 672 0
I 544 928 592 928 0 0.5 5
I 432 1200 480 1200 0 0.5 5
I 368 1024 416 1024 0 0.5 5
I 480 752 528 752 0 0.5 5
I 592 480 640 480 0 0.5 5

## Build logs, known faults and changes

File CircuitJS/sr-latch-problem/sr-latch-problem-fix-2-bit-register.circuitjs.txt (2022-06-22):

$ 1 0.000005 10.20027730826997 50 5 43 5e-11
w 496 1616 496 1648 0
w 608 1616 496 1616 0
w 624 1648 624 1728 0
w 496 1648 528 1648 0
180 560 1648 624 1648 0 0.1 10000000000 100000000
w 528 1648 528 1680 0
w 592 1664 592 1680 0
w 592 1680 528 1680 0
w 560 1648 528 1648 0
w 560 1728 528 1728 0
w 592 1760 528 1760 0
w 592 1744 592 1760 0
w 528 1728 528 1760 0
180 560 1728 624 1728 0 0.1 10000000000 100000000
w 496 1728 528 1728 0
w 176 1728 112 1728 0
w 192 1728 176 1728 0
150 432 1728 496 1728 0 2 0 5
w 192 1712 432 1712 0
w 192 1728 192 1712 0
w 192 1744 192 1728 0
w 208 1744 192 1744 0
w 256 1744 240 1744 0
w 304 1744 288 1744 0
w 352 1744 336 1744 0
w 400 1744 384 1744 0
I 400 1744 432 1744 0 0.5 5
I 352 1744 384 1744 0 0.5 5
I 304 1744 336 1744 0 0.5 5
I 256 1744 288 1744 0 0.5 5
I 208 1744 240 1744 0 0.5 5
g 112 1744 112 1760 0 0
v 112 1744 112 1728 0 0 40 5 0 0 0.5
w 672 384 688 384 0
w 672 384 640 384 0
w 672 336 672 384 0
w 688 304 656 304 0
w 720 384 688 384 0
w 752 384 784 384 0
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
x 523 357 569 360 4 24 CLK
w 544 368 496 368 0
I 448 224 480 224 0 0.5 5
I 496 224 528 224 0 0.5 5
I 544 224 576 224 0 0.5 5
I 592 224 624 224 0 0.5 5
I 640 224 672 224 0 0.5 5
w 640 224 624 224 0
w 592 224 576 224 0
w 544 224 528 224 0
w 496 224 480 224 0
w 448 224 432 224 0
w 432 224 432 208 0
w 432 208 432 192 0
w 432 192 672 192 0
150 672 208 736 208 0 2 0 5
w 432 368 448 368 0
w 496 368 448 368 0
w 432 208 416 208 0
x 355 201 401 204 4 24 CLK
w 432 368 400 368 0
w 400 368 400 272 0
w 400 272 400 256 0
w 416 208 352 208 0
w 656 448 688 448 0
w 416 256 736 256 0
w 416 256 400 256 0
w 736 208 768 208 0
w 768 208 784 208 0
w 784 208 784 256 0
w 784 256 736 256 0
w 816 320 816 560 0
152 320 464 400 464 0 2 0 5
150 176 432 240 432 0 2 0 5
150 176 512 240 512 0 2 0 5
I 96 416 176 416 0 0.5 5
w 64 416 96 416 0
w 64 416 16 416 0
w 64 416 64 496 0
w 64 496 176 496 0
w 320 448 256 448 0
w 256 448 256 432 0
w 256 432 240 432 0
w 320 480 256 480 0
w 256 480 256 512 0
w 256 512 240 512 0
w 176 448 96 448 0
w 96 448 96 512 0
w 96 512 16 512 0
w 176 528 -64 528 0
w 400 464 432 464 0
x 102 391 228 394 4 24 Feedbacker
x 15 504 33 507 4 24 Q
x -62 518 -38 521 4 24 IN
x -63 405 -24 408 4 24 WR
w 0 512 16 512 0
w 0 512 0 560 0
w 0 560 816 560 0
w 16 416 -64 416 0
w 992 320 960 320 0
w 896 320 816 320 0
180 896 320 960 320 0 0.1 10000000000 100000000
w 928 336 928 384 0
x 945 312 995 315 4 24 OUT
x 934 381 967 384 4 24 EN
207 -64 416 -112 416 4 WR
207 -64 528 -112 528 4 IN
207 352 208 304 208 4 CLK
207 928 384 928 432 4 EN
207 992 320 1040 320 4 OUT

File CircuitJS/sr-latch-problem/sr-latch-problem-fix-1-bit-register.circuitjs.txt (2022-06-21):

$ 1 0.000005 10.20027730826997 50 5 43 5e-11
w 736 432 704 432 0
v 224 720 224 704 0 0 40 5 0 0 0.5
g 224 720 224 736 0 0
I 320 720 352 720 0 0.5 5
I 368 720 400 720 0 0.5 5
I 416 720 448 720 0 0.5 5
I 464 720 496 720 0 0.5 5
I 512 720 544 720 0 0.5 5
w 512 720 496 720 0
w 464 720 448 720 0
w 416 720 400 720 0
w 368 720 352 720 0
w 320 720 304 720 0
w 304 720 304 704 0
w 304 704 304 688 0
w 304 688 544 688 0
150 544 704 608 704 0 2 0 5
w 304 704 288 704 0
w 288 704 224 704 0
w 608 704 640 704 0
g 976 384 976 400 0 0
v 976 384 976 368 0 0 40 5 0 0 0.5
180 944 304 1008 304 0 0.1 10000000000 100000000
w 944 304 864 304 0
s 976 368 976 320 0 1 false
w 1040 304 1008 304 0
s -48 512 32 512 0 0 false
w -80 32 -80 144 0
w 400 32 -80 32 0
w 400 0 400 32 0
w -80 224 -80 144 0
w 400 224 -80 224 0
w 400 192 400 224 0
w 496 0 400 0 0
w 560 0 528 0 0
g 560 -48 560 -64 0 0
v 560 -48 560 0 0 0 40 5 0 0 0.5
s 976 160 1040 160 0 1 false
w 960 176 960 160 0
v 960 192 960 176 0 0 40 5 0 0 0.5
g 960 192 960 208 0 0
w 976 160 960 160 0
x 1016 148 1065 151 4 24 BUS
w 1040 304 1040 560 0
w 992 560 1040 560 0
w 1040 304 1040 160 0
w -48 560 992 560 0
w -48 512 -48 560 0
w -48 400 -16 400 0
w -48 192 -48 400 0
w -32 192 -48 192 0
w 144 192 -32 192 0
w 144 192 144 176 0
w 64 400 16 400 0
w 48 544 864 544 0
w 48 496 48 544 0
w 48 496 64 496 0
x -29 374 36 377 4 24 LOAD
x -17 486 20 489 4 24 BIT
x 63 488 81 491 4 24 Q
x 150 375 276 378 4 24 Feedbacker
w 448 448 480 448 0
w 224 512 32 512 0
w 144 496 64 496 0
w 144 432 144 496 0
w 224 432 144 432 0
w 304 496 288 496 0
w 304 464 304 496 0
w 368 464 304 464 0
w 304 416 288 416 0
w 304 432 304 416 0
w 368 432 304 432 0
w 112 480 224 480 0
w 112 400 112 480 0
w 112 400 64 400 0
w 112 400 144 400 0
I 144 400 224 400 0 0.5 5
150 224 496 288 496 0 2 0 5
150 224 416 288 416 0 2 0 5
152 368 448 448 448 0 2 0 5
w 864 304 864 544 0
w 832 240 784 240 0
w 832 192 832 240 0
w 816 192 832 192 0
w 784 192 816 192 0
w 464 240 448 240 0
w 464 240 784 240 0
g 144 128 144 112 0 0
v 144 128 144 176 0 0 40 5 0 0 0.5
s -16 400 16 400 0 0 false
w 464 192 400 192 0
w 448 256 448 240 0
w 448 352 448 256 0
w 480 352 448 352 0
x 487 -17 533 -14 4 24 CLK
w 480 192 464 192 0
s 496 0 528 0 0 0 true
w 544 352 496 352 0
w 480 352 496 352 0
150 720 192 784 192 0 2 0 5
w 480 176 720 176 0
w 480 192 480 176 0
w 480 208 480 192 0
w 496 208 480 208 0
w 544 208 528 208 0
w 592 208 576 208 0
w 640 208 624 208 0
w 688 208 672 208 0
I 688 208 720 208 0 0.5 5
I 640 208 672 208 0 0.5 5
I 592 208 624 208 0 0.5 5
I 544 208 576 208 0 0.5 5
I 496 208 528 208 0 0.5 5
w 592 352 544 352 0
x 571 341 617 344 4 24 CLK
x 816 452 834 455 6 24 Q
x 815 295 833 298 4 24 Q
x 731 278 748 281 4 24 R
w 480 336 480 448 0
w 640 448 480 448 0
w 640 272 480 272 0
I 480 336 480 272 0 0.5 5
w 624 304 640 304 0
w 624 352 624 304 0
w 624 416 640 416 0
w 624 352 624 416 0
w 592 352 624 352 0
150 640 432 704 432 0 2 0 5
150 640 288 704 288 0 2 0 5
w 832 304 864 304 0
153 736 304 832 304 0 2 0 5
153 736 416 832 416 0 2 5 5
w 832 304 832 336 0
w 832 336 832 352 0
w 832 352 704 352 0
w 704 352 704 384 0
w 832 416 832 384 0
w 704 384 704 400 0
w 704 400 736 400 0
w 832 384 832 368 0
w 832 368 720 368 0
w 720 368 720 320 0
w 720 320 736 320 0
180 672 704 736 704 0 0.1 10000000000 100000000
w 640 704 640 736 0
w 704 720 704 736 0
w 704 736 640 736 0
w 672 704 640 704 0
w 672 624 640 624 0
w 704 656 640 656 0
w 704 640 704 656 0
w 640 624 640 656 0
180 672 624 736 624 0 0.1 10000000000 100000000
w 608 624 640 624 0
w 736 288 736 624 0
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

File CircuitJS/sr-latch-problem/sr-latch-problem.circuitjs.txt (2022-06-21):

$ 1 0.000005 0.6798259793203881 50 5 50 5e-11
w 720 320 736 320 0
w 720 368 720 320 0
w 832 368 720 368 0
w 832 384 832 368 0
w 704 400 736 400 0
w 704 384 704 400 0
w 832 416 832 384 0
w 704 352 704 384 0
w 832 352 704 352 0
w 832 336 832 352 0
w 832 304 832 336 0
153 736 416 832 416 0 2 5 5
153 736 304 832 304 0 2 5 5
w 832 304 864 304 0
w 832 416 864 416 0
150 640 288 704 288 0 2 0 5
150 640 432 704 432 0 2 0 5
w 592 352 624 352 0
w 624 352 624 416 0
w 624 416 640 416 0
w 624 352 624 304 0
w 624 304 640 304 0
I 480 336 480 272 0 0.5 5
w 640 272 480 272 0
w 640 448 480 448 0
w 480 336 480 448 0
x 731 278 748 281 4 24 R
x 734 456 750 459 4 24 S
x 815 295 833 298 4 24 Q
x 816 452 834 455 6 24 Q
x 571 341 617 344 4 24 CLK
w 592 352 544 352 0
I 496 208 528 208 0 0.5 5
I 544 208 576 208 0 0.5 5
I 592 208 624 208 0 0.5 5
I 640 208 672 208 0 0.5 5
I 688 208 720 208 0 0.5 5
w 688 208 672 208 0
w 640 208 624 208 0
w 592 208 576 208 0
w 544 208 528 208 0
w 496 208 480 208 0
w 480 208 480 192 0
w 480 192 480 176 0
w 480 176 720 176 0
150 720 192 784 192 0 2 0 5
w 480 352 496 352 0
w 544 352 496 352 0
s 496 0 528 0 0 0 true
w 480 192 464 192 0
x 487 -17 533 -14 4 24 CLK
w 480 352 448 352 0
w 448 352 448 256 0
w 448 256 448 240 0
w 464 192 400 192 0
s -16 400 16 400 0 0 false
v 144 128 144 176 0 0 40 5 0 0 0.5
g 144 128 144 112 0 0
w 464 240 784 240 0
w 464 240 448 240 0
w 784 192 816 192 0
w 816 192 832 192 0
w 832 192 832 240 0
w 832 240 784 240 0
152 368 448 448 448 0 2 0 5
150 224 416 288 416 0 2 0 5
150 224 496 288 496 0 2 0 5
I 144 400 224 400 0 0.5 5
w 112 400 144 400 0
w 112 400 64 400 0
w 112 400 112 480 0
w 112 480 224 480 0
w 368 432 304 432 0
w 304 432 304 416 0
w 304 416 288 416 0
w 368 464 304 464 0
w 304 464 304 496 0
w 304 496 288 496 0
w 224 432 144 432 0
w 144 432 144 496 0
w 144 496 64 496 0
w 224 512 32 512 0
w 448 448 480 448 0
x 150 375 276 378 4 24 Feedbacker
x 63 488 81 491 4 24 Q
x -17 486 20 489 4 24 BIT
x -29 374 36 377 4 24 LOAD
w 48 496 64 496 0
w 48 496 48 544 0
w 48 544 864 544 0
w 64 400 16 400 0
w 144 192 144 176 0
w 144 192 -32 192 0
w -32 192 -48 192 0
w -48 192 -48 400 0
w -48 400 -16 400 0
w -48 512 -48 560 0
w -48 560 992 560 0
w 1040 304 1040 160 0
w 992 560 1040 560 0
w 1040 304 1040 560 0
x 1016 148 1065 151 4 24 BUS
w 976 160 960 160 0
g 960 192 960 208 0 0
v 960 192 960 176 0 0 40 5 0 0 0.5
w 960 176 960 160 0
s 976 160 1040 160 0 1 false
v 560 -48 560 0 0 0 40 5 0 0 0.5
g 560 -48 560 -64 0 0
w 560 0 528 0 0
w 496 0 400 0 0
w 400 192 400 224 0
w 400 224 -80 224 0
w -80 224 -80 144 0
w 400 0 400 32 0
w 400 32 -80 32 0
w -80 32 -80 144 0
s -48 512 32 512 0 0 false
w 1040 304 1008 304 0
s 976 368 976 320 0 1 false
180 944 304 1008 304 0 0.1 10000000000 100000000
v 976 384 976 368 0 0 40 5 0 0 0.5
g 976 384 976 400 0 0

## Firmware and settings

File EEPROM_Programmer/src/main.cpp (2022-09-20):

#include <Arduino.h>

/**
 * We need to control a EEPROM (AT28C16), which has total of 21 pins:
 * - 11 pins for the address
 * - 8 pins for the data
 * - 2 pins for controlling it
 * We are using two shift registers. Each of them is 8 bit.
 * That gives us total of 16 bits.
 * The idea is to overcome the problem that Arduino Nano has only 12 digital pins.
 * The shift registers are build using JK Flip Flops. You can store multiple bits in them.
 * The ones that we are using (74HC595) need only 3 pins to be controlled.
 * If we control them with the Arduino we lose 3 pins, but gain 5 more.
 * If we chain two shift registers we lose 3 pins, but gain 13 more.
 * - Note that these additional pins that we achieved with the shift register are perfect only for pins
 * that doesn't require timing.
 */

#define EEPROM_IO_START_PIN 5
#define EEPROM_IO_END_PIN 12
#define EEPROM_WE_PIN 13

#define SHIFT_REGISTER_SER_PIN 2
#define SHIFT_REGISTER_RCLK_PIN 3
#define SHIFT_REGISTER_SR_CLK_PIN 4

#define BAUD_RATE 9600

#define MS 1
#define US 2

#define DECIMAL 10
#define HEX 16
#define BINARY 2

/**
 * Because, we have many control signals we can't use a single EEPROM.
 * ! Single EEPROM have only 8 outputs, which can't cover all signals and thus we can't active them.
 * That means we must use 2 EEPROMs and program them separately. For the same address program first half and then the second.
 * For easier programming the eeproms, instead of each time making the bits for a given microinstruction we can pre-define where the bits for a given
 * control signal to be activated need to be and the using bitwise operators create the final control signals for single microinstruction.
 */

//First EEPROM
#define HLT_CS 0b10000000
#define MI_CS 0b01000000
#define RI_CS 0b00100000
#define RO_CS 0b00010000
#define IO_CS 0b00001000
#define II_CS 0b00000100
#define AI_CS 0b00000010
#define AO_CS 0b00000001

//Second EEPROM
#define EO_CS  0b10000000
#define SU_CS  0b01000000
#define BI_CS  0b00100000
#define OI_CS  0b00010000
#define CE_CS  0b00001000
#define CO_CS  0b00000100
#define J_CS   0b00000010

const uint8_t LDA_INSTRUCTION_CODE = 0b0000;
const uint8_t LDB_INSTRUCTION_CODE = 0b0001;
const uint8_t ADD_INSTRUCTION_CODE = 0b0010;
const uint8_t SUB_INSTRUCTION_CODE = 0b0011;
const uint8_t STA_INSTRUCTION_CODE = 0b0100;
const uint8_t LDI_INSTRUCTION_CODE = 0b0101;
const uint8_t JMP_INSTRUCTION_CODE = 0b0110;
const uint8_t OUT_INSTRUCTION_CODE = 0b0111;
const uint8_t HLT_INSTRUCTION_CODE = 0b1000;

/**
 * Each index corresponds to the digit.
 * Index 0 = Digit 0
 * Index 1 = Digit 9
 * Up to Index 9.
 *
 * (7) HIGH, LOW, LOW, HIGH, HIGH, LOW, LOW = 0b00110010
 * (8) HIGH, HIGH, HIGH, HIGH, HIGH, HIGH, HIGH = 0b11111110
 * (9) HIGH, LOW, LOW, HIGH, HIGH, HIGH, HIGH = 0b11110010
 */
byte segmentDisplayMappingDigits[10] = {0b01111110, 0b00010010, 0b10111100, 0b10110110, 0b11010010, 0b11100110, 0b11101110, 0b00110010, 0b11111110, 0b11110010};

/**
 * Index 0 = NOTHING
 * Index 1 = -
 */
byte segmentDisplayCharacterMapping[2] = {0b00000000, 0b10000000};

void digitalWriteBetween(const unsigned int& startPin, const unsigned int& endPin, const unsigned int& value);

unsigned int digitalReadBetween(const unsigned int& startPin, const unsigned int& endPin);

void delay(const unsigned int& timeValue, const int& timeUnit);

void clockPin(const uint8_t& pin, const bool& val, const unsigned int& timeValue, const int& timeUnit);

void clockPin(const uint8_t& pin, const bool& val);

template<size_t N>
void pinModes(int (& pins)[N], const bool& mode);

void setShiftRegisterBits(const uint16_t& bits, const uint8_t& bitOrder = MSBFIRST);

void setEEPROMPins(const uint16_t& address, const bool& outputEnable, const uint8_t& bitOrder = MSBFIRST);

uint8_t readEEPROMAddress(const uint16_t& address);

void printEEPROMAddressBinary(const uint16_t& address);

void printEEPROMAddressDecimal(const uint16_t& address);

void printEEPROMAddressHex(const uint16_t& address);

void printEEPROMAddress(const uint16_t& address, const uint8_t& format);

void printEEPROMAddress(const uint16_t& from, const uint16_t& to, const uint8_t& format);

void setEEPROMAddressData(const uint16_t& address, const uint8_t& data, const uint8_t& bitOrder = MSBFIRST);

void programEEPROM3BitsSegmentDecoder();

void programEEPROM8BitsSegmentDecoder();

uint16_t generateMicroinstructionAddress(const uint8_t& step, const uint8_t& instruction);

/*
*
* Address:
* A0/3 Instruction (4 bits)
* A4/6: Microinstruction (3 bits)
* A7/11: Nothing Yet (5 bits all 0)
*
* Data:
* First EEPROM: HLT, MI, RI, RO, IO, II, AI, AO
* Second EEPROM: EO, SU, BI, OI, CE, CO, J, NOTHING (0)
 *
 * Example:
 *
 * Instruction | N Microinstruction | Activate Control Signals (HLT, MI, RI, RO, IO ... J)
 *
 * 0001             000                 0100000000000010
 * 0001             001                 0001010000000100
 * 0001             010                 0100100000000000
 * 0001             011                 0001001000000000
 *
 * 0b00000{Microinstruction 3 bits}{Instruction 4 Bits}
 * 0b00000{Step 3 bits}{Code 4 Bits}
 * */
void programFirstEEPROM() {

    setEEPROMAddressData(generateMicroinstructionAddress(0, LDA_INSTRUCTION_CODE), MI_CS);
    setEEPROMAddressData(generateMicroinstructionAddress(1, LDA_INSTRUCTION_CODE), RO_CS | II_CS);
    setEEPROMAddressData(generateMicroinstructionAddress(2, LDA_INSTRUCTION_CODE), MI_CS | IO_CS);
    setEEPROMAddressData(generateMicroinstructionAddress(3, LDA_INSTRUCTION_CODE), RO_CS | AI_CS);
    setEEPROMAddressData(generateMicroinstructionAddress(4, LDA_INSTRUCTION_CODE), 0);

    setEEPROMAddressData(generateMicroinstructionAddress(0, LDB_INSTRUCTION_CODE), MI_CS);
    setEEPROMAddressData(generateMicroinstructionAddress(1, LDB_INSTRUCTION_CODE), RO_CS | II_CS);
    setEEPROMAddressData(generateMicroinstructionAddress(2, LDB_INSTRUCTION_CODE), MI_CS | IO_CS);
    setEEPROMAddressData(generateMicroinstructionAddress(3, LDB_INSTRUCTION_CODE), RO_CS);
    setEEPROMAddressData(generateMicroinstructionAddress(4, LDB_INSTRUCTION_CODE), 0);

    setEEPROMAddressData(generateMicroinstructionAddress(0, ADD_INSTRUCTION_CODE), MI_CS);
    setEEPROMAddressData(generateMicroinstructionAddress(1, ADD_INSTRUCTION_CODE), RO_CS | II_CS);
    setEEPROMAddressData(generateMicroinstructionAddress(2, ADD_INSTRUCTION_CODE), MI_CS | IO_CS);
    setEEPROMAddressData(generateMicroinstructionAddress(3, ADD_INSTRUCTION_CODE), RI_CS);
    setEEPROMAddressData(generateMicroinstructionAddress(4, ADD_INSTRUCTION_CODE), 0);

    setEEPROMAddressData(generateMicroinstructionAddress(0, SUB_INSTRUCTION_CODE), MI_CS);
    setEEPROMAddressData(generateMicroinstructionAddress(1, SUB_INSTRUCTION_CODE), RO_CS | II_CS);
    setEEPROMAddressData(generateMicroinstructionAddress(2, SUB_INSTRUCTION_CODE), MI_CS | IO_CS);
    setEEPROMAddressData(generateMicroinstructionAddress(3, SUB_INSTRUCTION_CODE), RO_CS);
    setEEPROMAddressData(generateMicroinstructionAddress(4, SUB_INSTRUCTION_CODE), AI_CS);

    setEEPROMAddressData(generateMicroinstructionAddress(0, STA_INSTRUCTION_CODE), MI_CS);
    setEEPROMAddressData(generateMicroinstructionAddress(1, STA_INSTRUCTION_CODE), RO_CS | II_CS);
    setEEPROMAddressData(generateMicroinstructionAddress(2, STA_INSTRUCTION_CODE), MI_CS | IO_CS);
    setEEPROMAddressData(generateMicroinstructionAddress(3, STA_INSTRUCTION_CODE), RI_CS | AO_CS);
    setEEPROMAddressData(generateMicroinstructionAddress(4, STA_INSTRUCTION_CODE), 0);

    setEEPROMAddressData(generateMicroinstructionAddress(0, LDI_INSTRUCTION_CODE), MI_CS);
    setEEPROMAddressData(generateMicroinstructionAddress(1, LDI_INSTRUCTION_CODE), RO_CS | II_CS);
    setEEPROMAddressData(generateMicroinstructionAddress(2, LDI_INSTRUCTION_CODE), IO_CS | AI_CS);
    setEEPROMAddressData(generateMicroinstructionAddress(3, LDI_INSTRUCTION_CODE), 0);
    setEEPROMAddressData(generateMicroinstructionAddress(4, LDI_INSTRUCTION_CODE), 0);

    setEEPROMAddressData(generateMicroinstructionAddress(0, JMP_INSTRUCTION_CODE), MI_CS);
    setEEPROMAddressData(generateMicroinstructionAddress(1, JMP_INSTRUCTION_CODE), RO_CS | II_CS);
    setEEPROMAddressData(generateMicroinstructionAddress(2, JMP_INSTRUCTION_CODE), IO_CS);
    setEEPROMAddressData(generateMicroinstructionAddress(3, JMP_INSTRUCTION_CODE), 0);
    setEEPROMAddressData(generateMicroinstructionAddress(4, JMP_INSTRUCTION_CODE), 0);

    setEEPROMAddressData(generateMicroinstructionAddress(0, OUT_INSTRUCTION_CODE), MI_CS);
    setEEPROMAddressData(generateMicroinstructionAddress(1, OUT_INSTRUCTION_CODE), RO_CS | II_CS);
    setEEPROMAddressData(generateMicroinstructionAddress(2, OUT_INSTRUCTION_CODE), AO_CS);
    setEEPROMAddressData(generateMicroinstructionAddress(3, OUT_INSTRUCTION_CODE), 0);
    setEEPROMAddressData(generateMicroinstructionAddress(4, OUT_INSTRUCTION_CODE), 0);

    setEEPROMAddressData(generateMicroinstructionAddress(0, HLT_INSTRUCTION_CODE), MI_CS);
    setEEPROMAddressData(generateMicroinstructionAddress(1, HLT_INSTRUCTION_CODE), RO_CS | II_CS);
    setEEPROMAddressData(generateMicroinstructionAddress(2, HLT_INSTRUCTION_CODE), HLT_CS);
    setEEPROMAddressData(generateMicroinstructionAddress(3, HLT_INSTRUCTION_CODE), 0);
    setEEPROMAddressData(generateMicroinstructionAddress(4, HLT_INSTRUCTION_CODE), 0);
}

void programSecondEEPROM() {

    setEEPROMAddressData(generateMicroinstructionAddress(0, LDA_INSTRUCTION_CODE), CO_CS);
    setEEPROMAddressData(generateMicroinstructionAddress(1, LDA_INSTRUCTION_CODE), CE_CS);
    setEEPROMAddressData(generateMicroinstructionAddress(2, LDA_INSTRUCTION_CODE), 0);
    setEEPROMAddressData(generateMicroinstructionAddress(3, LDA_INSTRUCTION_CODE), 0);
    setEEPROMAddressData(generateMicroinstructionAddress(4, LDA_INSTRUCTION_CODE), 0);

    setEEPROMAddressData(generateMicroinstructionAddress(0, LDB_INSTRUCTION_CODE), CO_CS);
    setEEPROMAddressData(generateMicroinstructionAddress(1, LDB_INSTRUCTION_CODE), CE_CS);
    setEEPROMAddressData(generateMicroinstructionAddress(2, LDB_INSTRUCTION_CODE), 0);
    setEEPROMAddressData(generateMicroinstructionAddress(3, LDB_INSTRUCTION_CODE), BI_CS);
    setEEPROMAddressData(generateMicroinstructionAddress(4, LDB_INSTRUCTION_CODE), 0);

    setEEPROMAddressData(generateMicroinstructionAddress(0, ADD_INSTRUCTION_CODE), CO_CS);
    setEEPROMAddressData(generateMicroinstructionAddress(1, ADD_INSTRUCTION_CODE), CE_CS);
    setEEPROMAddressData(generateMicroinstructionAddress(2, ADD_INSTRUCTION_CODE), 0);
    setEEPROMAddressData(generateMicroinstructionAddress(3, ADD_INSTRUCTION_CODE), EO_CS);
    setEEPROMAddressData(generateMicroinstructionAddress(4, ADD_INSTRUCTION_CODE), 0);

    setEEPROMAddressData(generateMicroinstructionAddress(0, SUB_INSTRUCTION_CODE), CO_CS);
    setEEPROMAddressData(generateMicroinstructionAddress(1, SUB_INSTRUCTION_CODE), CE_CS);
    setEEPROMAddressData(generateMicroinstructionAddress(2, SUB_INSTRUCTION_CODE), 0);
    setEEPROMAddressData(generateMicroinstructionAddress(3, SUB_INSTRUCTION_CODE), EO_CS | SU_CS);
    setEEPROMAddressData(generateMicroinstructionAddress(4, SUB_INSTRUCTION_CODE), 0);

    setEEPROMAddressData(generateMicroinstructionAddress(0, STA_INSTRUCTION_CODE), CO_CS);
    setEEPROMAddressData(generateMicroinstructionAddress(1, STA_INSTRUCTION_CODE), CE_CS);
    setEEPROMAddressData(generateMicroinstructionAddress(2, STA_INSTRUCTION_CODE), 0);
    setEEPROMAddressData(generateMicroinstructionAddress(3, STA_INSTRUCTION_CODE), 0);
    setEEPROMAddressData(generateMicroinstructionAddress(4, STA_INSTRUCTION_CODE), 0);

    setEEPROMAddressData(generateMicroinstructionAddress(0, LDI_INSTRUCTION_CODE), CO_CS);
    setEEPROMAddressData(generateMicroinstructionAddress(1, LDI_INSTRUCTION_CODE), CE_CS);
    setEEPROMAddressData(generateMicroinstructionAddress(2, LDI_INSTRUCTION_CODE), 0);
    setEEPROMAddressData(generateMicroinstructionAddress(3, LDI_INSTRUCTION_CODE), 0);
    setEEPROMAddressData(generateMicroinstructionAddress(4, LDI_INSTRUCTION_CODE), 0);

    setEEPROMAddressData(generateMicroinstructionAddress(0, JMP_INSTRUCTION_CODE), CO_CS);
    setEEPROMAddressData(generateMicroinstructionAddress(1, JMP_INSTRUCTION_CODE), CE_CS);
    setEEPROMAddressData(generateMicroinstructionAddress(2, JMP_INSTRUCTION_CODE), J_CS);
    setEEPROMAddressData(generateMicroinstructionAddress(3, JMP_INSTRUCTION_CODE), 0);
    setEEPROMAddressData(generateMicroinstructionAddress(4, JMP_INSTRUCTION_CODE), 0);

    setEEPROMAddressData(generateMicroinstructionAddress(0, OUT_INSTRUCTION_CODE), CO_CS);
    setEEPROMAddressData(generateMicroinstructionAddress(1, OUT_INSTRUCTION_CODE), CE_CS);
    setEEPROMAddressData(generateMicroinstructionAddress(2, OUT_INSTRUCTION_CODE), OI_CS);
    setEEPROMAddressData(generateMicroinstructionAddress(3, OUT_INSTRUCTION_CODE), 0);
    setEEPROMAddressData(generateMicroinstructionAddress(4, OUT_INSTRUCTION_CODE), 0);

    setEEPROMAddressData(generateMicroinstructionAddress(0, HLT_INSTRUCTION_CODE), CO_CS);
    setEEPROMAddressData(generateMicroinstructionAddress(1, HLT_INSTRUCTION_CODE), CE_CS);
    setEEPROMAddressData(generateMicroinstructionAddress(2, HLT_INSTRUCTION_CODE), 0);
    setEEPROMAddressData(generateMicroinstructionAddress(3, HLT_INSTRUCTION_CODE), 0);
    setEEPROMAddressData(generateMicroinstructionAddress(4, HLT_INSTRUCTION_CODE), 0);
}

void setup() {
    Serial.begin(BAUD_RATE);
    Serial.println("EEPROM Start!");

    digitalWrite(EEPROM_WE_PIN, HIGH);

    int outputPins[4] = {EEPROM_WE_PIN, SHIFT_REGISTER_SER_PIN, SHIFT_REGISTER_RCLK_PIN, SHIFT_REGISTER_SR_CLK_PIN};
    pinModes(outputPins, OUTPUT);



    Serial.println("Started programming!");
    //programFirstEEPROM();
    programSecondEEPROM();
    Serial.println("Finished programming!");
}

void loop() {

}

/*
 * We have 8 bit number. It implements two's complement.
 * That means 1 bit for sign and 7 bit for the number.
 * 1000 0000 = -128
 * 1111 1111 = -1
 * 0000 0000 = 0
 * 0111 1111 = 127
 * */

void programEEPROM8BitsSegmentDecoder() {

    for (int programNumber = -128; programNumber <= 127; ++programNumber) {

        bool isPositive = programNumber >= 0;

        /**
         * Example:
         * programNumber = -103 = 0b10011001 (Two's Complement)
         * The (0b10 << 8) | programNumberConverted will not work. The result will still be 0b10011001 instead of 0b1010011001
         * Looks like the number must be 0b10011001, but positive to work the shifting.
         * That means 0b10011001 = 153
         * To keep the bits, but turn it into positive just move it to uint8_t. That way the shifting will work as expected.
         */
        uint8_t programNumberConverted = programNumber;

        int combination0Address = (0b00 << 8) | programNumberConverted;
        int combination1Address = (0b10 << 8) | programNumberConverted;
        int combination2Address = (0b01 << 8) | programNumberConverted;
        int combination3Address = (0b11 << 8) | programNumberConverted;

        int programNumberPositive = abs(programNumber);
        int onesDigit = programNumberPositive % 10;
        int secondDigit = (programNumberPositive / 10) % 10;
        int thirdDigit = (programNumberPositive / 100) % 10;

        setEEPROMAddressData(combination0Address, segmentDisplayMappingDigits[thirdDigit]);
        setEEPROMAddressData(combination1Address, segmentDisplayMappingDigits[secondDigit]);
        setEEPROMAddressData(combination2Address, segmentDisplayMappingDigits[onesDigit]);
        setEEPROMAddressData(combination3Address, isPositive ? segmentDisplayCharacterMapping[0] : segmentDisplayCharacterMapping[1]);
    }
}

void programEEPROM3BitsSegmentDecoder() {
    Serial.println("Programming EEPROM as decoder for 3 bit to display decoder.");
    setEEPROMAddressData(0, 0b01111110);
    setEEPROMAddressData(1, 0b00010010);
    setEEPROMAddressData(2, 0b10111100);
    setEEPROMAddressData(3, 0b10110110);
    setEEPROMAddressData(4, 0b11010010);
    setEEPROMAddressData(5, 0b11100110);
    setEEPROMAddressData(6, 0b11101110);
    setEEPROMAddressData(7, 0b00110010);
    Serial.println("Programmed EEPROM as decoder for 3 bit to display decoder.");

    //printEEPROMAddress(0, 7, BINARY);
}

/**
 * Example:
 * Let's say we have the OUT instruction.
 * The OUT instruction unique code (4 bit) is 0110.
 * The OUT instruction needs 5 total microinstruction.
 *       EEPROM Addr. |  Control Signals
 * 0:  0b000000000110      0b01000000
 * 1:  0b000000010110      0b00010100
 * 2:  0b000000100110      0b00000001
 * 3:  0b000000110110      0b00000000
 * 4:  0b000001000110      0b00000000
 *
 * Where EEPROM Address's patter is the following:
 * 0b00000{N Microinstruction (3 bits)}{Instruction (4 Bits)}
 *
 * Instead of programming the eeprom the hard way and getting lost while writing the bits for each instruction's microinstructions:
 *  setEEPROMAddressData(0b000000000110, 0b01000000); //Microinstruction: 1;
 *  setEEPROMAddressData(0b000000010110, 0b00010100); //Microinstruction: 2;
 *  setEEPROMAddressData(0b000000100110, 0b00000001); //Microinstruction: 3;
 *  setEEPROMAddressData(0b000000110110, 0b00000000); //Microinstruction: 4;
 *  setEEPROMAddressData(0b000001000110, 0b00000000); //Microinstruction: 5;
 * You can use that method to easily generate them and not get lost in the bits:
 *  setEEPROMAddressData(generateMicroinstructionAddress(0, OUT_INSTRUCTION_CODE), 0b01000000); //Microinstruction: 1;
 *  setEEPROMAddressData(generateMicroinstructionAddress(1, OUT_INSTRUCTION_CODE), 0b00010100); //Microinstruction: 2;
 *  setEEPROMAddressData(generateMicroinstructionAddress(2, OUT_INSTRUCTION_CODE), 0b00000001); //Microinstruction: 3;
 *  setEEPROMAddressData(generateMicroinstructionAddress(3, OUT_INSTRUCTION_CODE), 0b00000000); //Microinstruction: 4;
 *  setEEPROMAddressData(generateMicroinstructionAddress(4, OUT_INSTRUCTION_CODE), 0b00000000); //Microinstruction: 5;
 *
 * @param step Which line of instruction is that.
 * @param code The unique code of the instruction
 */
uint16_t generateMicroinstructionAddress(const uint8_t& step, const uint8_t& code) {
    return 0b000000000000 | (step << 4) | code;;
}

/**
 * Will shift the bits to the 74HC595 shift register.
 * We are using the Arduino's prebuild shift out function, but it is limited to shifting only 8 bits at a time.
 * Thus we use it twice.
 * The prebuild function will place each of the provided bits on the SER_PIN and clock the SR_CLK pin, which will store them.
 * The shift register has two storages. Shift and Storage Register. The outputed bits from it are from the Storage Register.
 * After storing the 16 bits in the shift register we clock the RCLK_PIN, which moves the stored bits in the Shift Register to the Storage Register.
 */
void setShiftRegisterBits(const uint16_t& bits, const uint8_t& bitOrder) {
    uint8_t msb = bits >> 8;
    uint8_t lsb = bits & 0b11111111;

    shiftOut(SHIFT_REGISTER_SER_PIN, SHIFT_REGISTER_SR_CLK_PIN, bitOrder, msb);
    shiftOut(SHIFT_REGISTER_SER_PIN, SHIFT_REGISTER_SR_CLK_PIN, bitOrder, lsb);

    clockPin(SHIFT_REGISTER_RCLK_PIN, HIGH);
}

/**
 * Sets the address of the EEPROM and if the EEPROM's output will be enabled.
 */
void setEEPROMPins(const uint16_t& address, const bool& outputEnable, const uint8_t& bitOrder) {
    uint16_t shiftOutData = (!outputEnable << 11) | address;

    setShiftRegisterBits(shiftOutData, bitOrder);
}

uint8_t readEEPROMAddress(const uint16_t& address) {

    setEEPROMPins(address, true);

    return digitalReadBetween(EEPROM_IO_START_PIN, EEPROM_IO_END_PIN);
}

void printEEPROMAddressBinary(const uint16_t& address) {

    uint8_t addressData = readEEPROMAddress(address);

    bool dataBits[8] = {};

    for (int i = 0; i < 8; ++i)
        dataBits[i] = (0b1 << (7 - i)) & addressData;

    char printBuffer[34];
    sprintf(printBuffer, "Address: %d Value: %d %d %d %d %d %d %d %d", address, dataBits[0], dataBits[1], dataBits[2], dataBits[3], dataBits[4], dataBits[5], dataBits[6], dataBits[7]);
    Serial.println(printBuffer);
}

void printEEPROMAddressDecimal(const uint16_t& address) {
    uint8_t addressData = readEEPROMAddress(address);

    char printBuffer[20];
    sprintf(printBuffer, "Address: %d Value: %d", address, addressData);
    Serial.println(printBuffer);
}

void printEEPROMAddressHex(const uint16_t& address) {
    uint8_t addressData = readEEPROMAddress(address);

    char printBuffer[20];
    sprintf(printBuffer, "Address: %d Value: %X", address, addressData);
    Serial.println(printBuffer);
}


void printEEPROMAddress(const uint16_t& address, const uint8_t& format) {

    switch (format) {

        case BINARY:
            return printEEPROMAddressBinary(address);

        case DECIMAL:
            return printEEPROMAddressDecimal(address);

        case HEX:
            return printEEPROMAddressHex(address);
    }

}

void printEEPROMAddress(const uint16_t& from, const uint16_t& to, const uint8_t& format) {

    for (uint16_t address = from; address <= to; ++address) {
        printEEPROMAddress(address, format);
    }
}

void setEEPROMAddressData(const uint16_t& address, const uint8_t& data, const uint8_t& bitOrder) {

    setEEPROMPins(address, false, bitOrder);

    digitalWriteBetween(EEPROM_IO_START_PIN, EEPROM_IO_END_PIN, data);

    clockPin(EEPROM_WE_PIN, LOW, 1, US);
    delay(10);
}

/*---------------- Utils ----------------*/
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

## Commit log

2022-05-02 latches schemantics
    [sr_latch.kicad_pcb, sr_latch.kicad_sch]
2022-05-02 74LS00 NAND Lib Symbol
    [d_latch.kicad_pcb, d_latch.kicad_sch, enable_switcher.kicad_pcb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]
2022-05-02 Fixed NOR & AND Libs grid
    [d_latch_bb_t_1.kicad_pcb, d_latch_bb_t_1.kicad_sch]
2022-05-02 Added the schemantics for the part of the D-latch bb testing
    [d_latch_bb_t_1.kicad_sch]
2022-05-02 Optimized the D Latch Test
    [d_latch_bb_t_1.kicad_sch]
2022-05-02 D latch full test schematics
    [d_latch_bb_t_2.kicad_pcb, d_latch_bb_t_2.kicad_sch]
2022-05-06 Edge dector schema using gates
    [edge_dector_gates.kicad_pcb, edge_dector_gates.kicad_sch]
2022-05-06 Notes for the enable switch schemantic
    [d_latch_bb_t_1.kicad_sch]
2022-05-07 Schemantics for the d flip flop
    [d_flip_flop_bb_t.kicad_pcb, d_flip_flop_bb_t.kicad_sch]
2022-05-07 Fixed the D Flip Flop
    [d_flip_flop_bb_t.kicad_sch]
2022-05-08 Flow Charts for the D Latch/Flip Flop
2022-05-09 R Divider + Comparators + Latch for the Timer
    [555_timer_internals.kicad_pcb, 555_timer_internals.kicad_sch]
2022-05-09 555 Timer Exploded view
2022-05-09 Notch & Note for the 555 timer
2022-05-12 Updated resources of the timer, ltspice test for capacitors. Readme new categories
    [555_timer_internals.kicad_sch]
2022-05-19 CircuitJS tests & doc update
2022-05-19 Created a 555 Timer from scratch
2022-05-22 Fixed typos, remove pin numbers, raw idea & circuitjs for the d latch
2022-05-22 DrawIo Diagrams for the D Latch
    [555_timer_internals.kicad_sch, d_latch.kicad_sch, simulator_test.kicad_pcb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]
2022-05-22 Fixed the 555 Timer Internals
    [555_timer_internals.kicad_sch]
2022-05-22 Updated the CircuitJS 555 Timer Discharge Resistance
2022-05-23 Set by step 555 timer creation in the docs + new circuitjs schem
2022-05-24 Finished the doc about the 555 Timer
2022-05-26 Monostable 555 Timer and Button Deboucing Doc Started
2022-05-28 Finished the doc for the switch debouncing methods
2022-05-30 Updated the Logism doc
    [digital_switch_idea.kicad_sch]
2022-05-30 Circuit Diagrams for the Logism
2022-06-01 Switch SPDT debouncing
2022-06-30 Summary for the ram
    [ram_write_signal_fix.kicad_pcb, ram_write_signal_fix.kicad_sch]
2022-07-29 Removed pre-set of pin mode for the read
2022-07-30 Decimal and Binary printing encanced
2022-07-30 Hex printing for the data of a adress
2022-08-02 EEPROM address print between
2022-08-07 Initial number test for whole flow
2022-09-12 fixed data bit oder
    [main.cpp]
